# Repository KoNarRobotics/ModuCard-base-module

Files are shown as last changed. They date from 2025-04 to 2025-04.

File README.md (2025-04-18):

# ModuCard Base Module

This repository provides a template design for creating modules in the ModuCard system. Each module is designed to seamlessly interface with the [ModuCard backplane](https://github.com/KoNarRobotics/ModuCard-backplane), enabling a modular and expandable robotics platform.
obraz

## Used tools:


## Features:

### Power section
- **Input voltage:** 12V from the backplane.  
- **Output voltage:** 3.3V @ 0.5A.

### ST-LINK
- Built-in **ST-LINK** connected to the backplane via USB interface.  
- Enables programming and debugging of the onboard MCU.

### CAN interface
- Two independent CAN buses: **CAN1** and **CAN2**.  
- Both connect with the backplane to facilitate communication between the onboard MCU and other modules in the system.

# How to Create a new module from this template
1. **Create a new repository**
2. **Copy files from this repository** to your new repository.  
3. **Rename the files:**
   - `base-module.kicad_pcb` → `<your-board-name>.kicad_pcb`
   - `base-module.kicad_sch` → `<your-board-name>.kicad_sch`
   - `base-module.kicad_pro` → `<your-board-name>.kicad_pro`
4. **Open the project** in KiCad.  
5. **Update page settings** in the schematic and PCB:
   - Change the **Title** to `ModuCard <your project name>`.  
   - Edit **Comment 2** to include your name in the `<author>` field.
6. Enjoy implementing your project!

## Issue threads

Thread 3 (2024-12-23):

Base Module Schematic

ArthorH, 2024-12-23:

Dominik-Workshop, 2025-02-13:
Updated components on the schematic to be from JLC component library.
Finalized schematic, cleared ERC errors. Schematic needs to be double checked, but any possible fixes will be done on branch #2, as mistakes in the schematic might come out during layout.

Dominik-Workshop, 2025-02-13:
Created MR #6 and merged to main.
Closing this issue.

Closed 2025-02-13.

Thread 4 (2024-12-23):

Base Module Verification

ArthorH, 2024-12-23:
PCB was finished in [#2]. It needs to be verified, that there are no mistakes in the design.

Dominik-Workshop, 2025-02-18:
Cleaned up the shematic, fixed found issues. Created MR [#9], merged to main

Closed 2025-02-18.

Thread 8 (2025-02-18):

Fix front panel component libraries

ArthorH, 2025-02-18:
Fix issues with footprint libraries

ArthorH, 2025-02-19:
Fixed all issues, added a new silkscreen, changed the designated spots for board information and boardhouse information, and added a QR code to the PCB.

Closed 2025-02-19.

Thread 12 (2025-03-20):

Fix issues found during bringup

Dominik-Workshop, 2025-03-20:
Following issues were found during bringup of [nav module](https://github.com/KoNarRobotics/ModuCard-nav-module) which is based on this template:
- no GND testpoints (minor issue)
- power indicator LEDs are too bright
- USB not working due to TVS's big capacitance (`U200` and `U802`)
- ST-LINK working only intermittently, due to wrong load capacitors for crystal osclillator (change `C707` and `C708` 33pF -> 18pF)
- ST-LINK LEDs are too dim

These issues should be fixed in next revision.

X-Lemon-X, 2025-03-26:
Tranzistor from stlinka usb-renum is making st link not pop up on USB

Dominik-Workshop, 2025-03-29:
`ST-LINK`'s resonator `Y700` has no `MPN`. We need to choose specific part, and only then we can change it's load capacitors.

Dominik-Workshop, 2025-04-13:
`Y700`'s MPN `3225-8.00-20-10-10/4B` (LCSC Part #  `C7424755`)

Dominik-Workshop, 2025-04-17:
It turned out, `Y700` that was sodlered wasn't `3225-8.00-20-10-10/4B`, and the one that was soldered had `10pF` of load capacitance.
Added `Y700` MPN info: `3225-8.00-20-10-10/4B` in the KiCad project. Next time we need to ensure we solder the correct resonator.

Closed 2025-04-17.

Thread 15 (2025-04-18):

Change name to ModuCard-BM-STM32H750VBT6 to avoid confusion

ArthorH, 2025-04-18:
Simple name change in order to avoid confusion

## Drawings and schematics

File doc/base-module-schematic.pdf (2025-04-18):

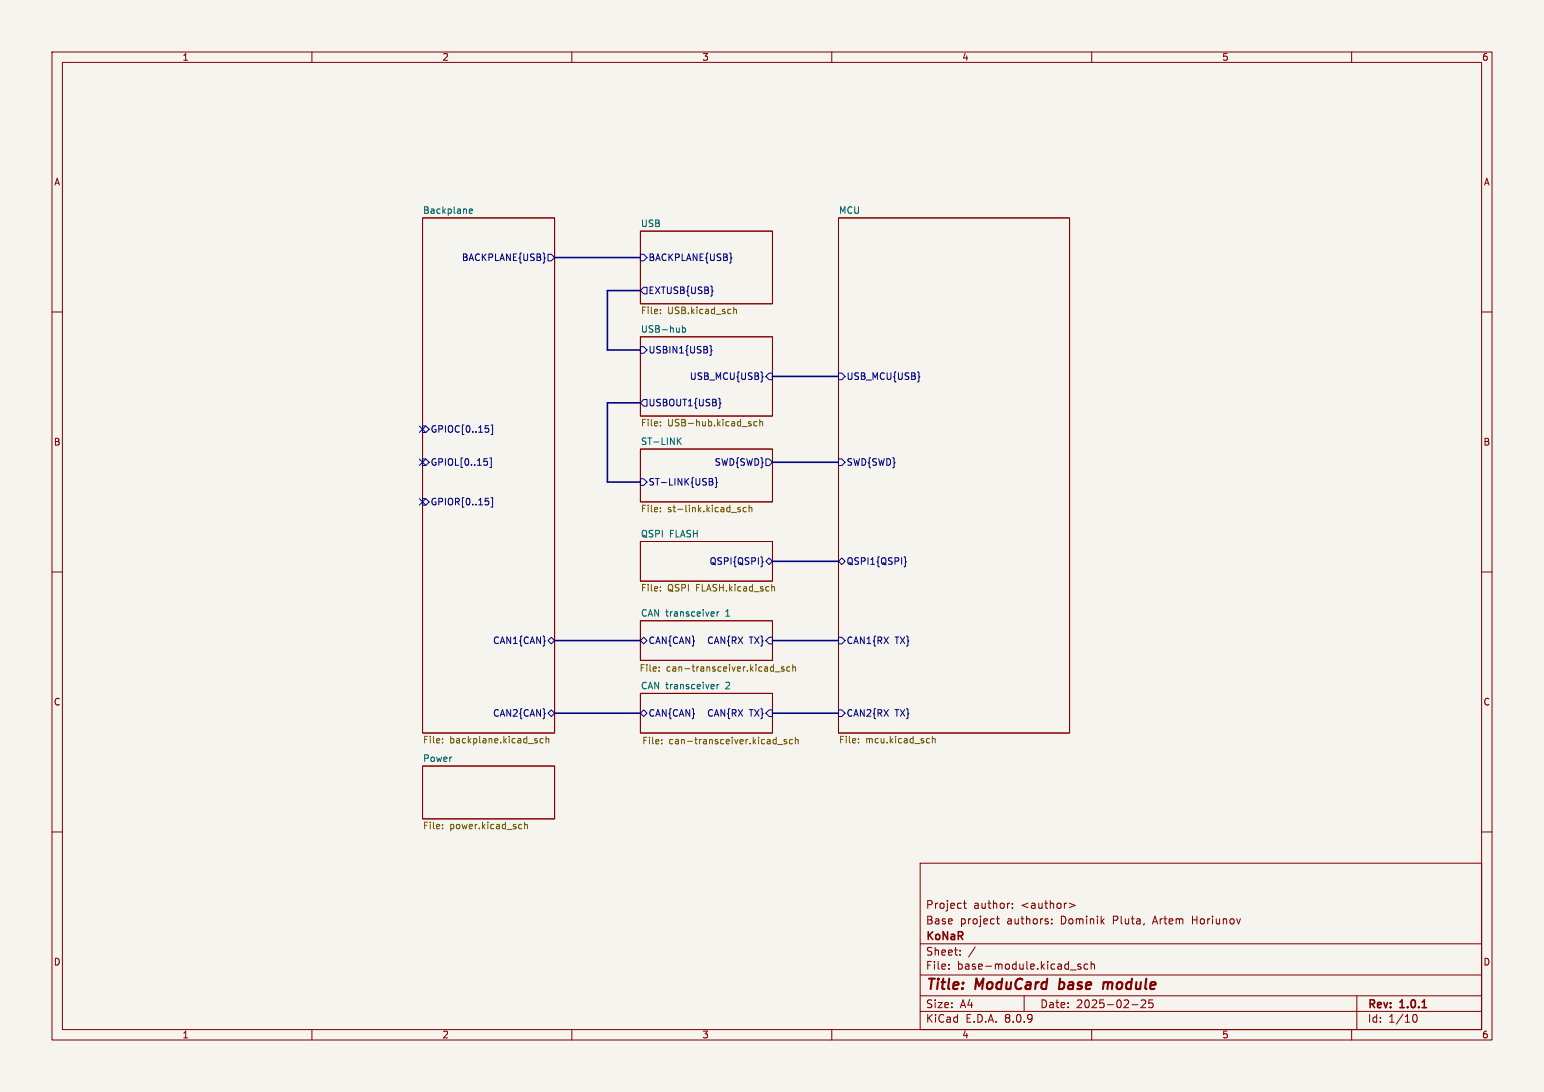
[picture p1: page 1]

Backplane File: backplane.kicad_sch
File: USB.kicad_sch QSPI{QSPI} QSPI FLASH

File: QSPI FLASH.kicad_sch USBIN1{USB}

SWD{SWD} ST-LINK

File: base-module.kicad_sch Sheet: / KoNaR

Id: 1/10 Title: ModuCard base module

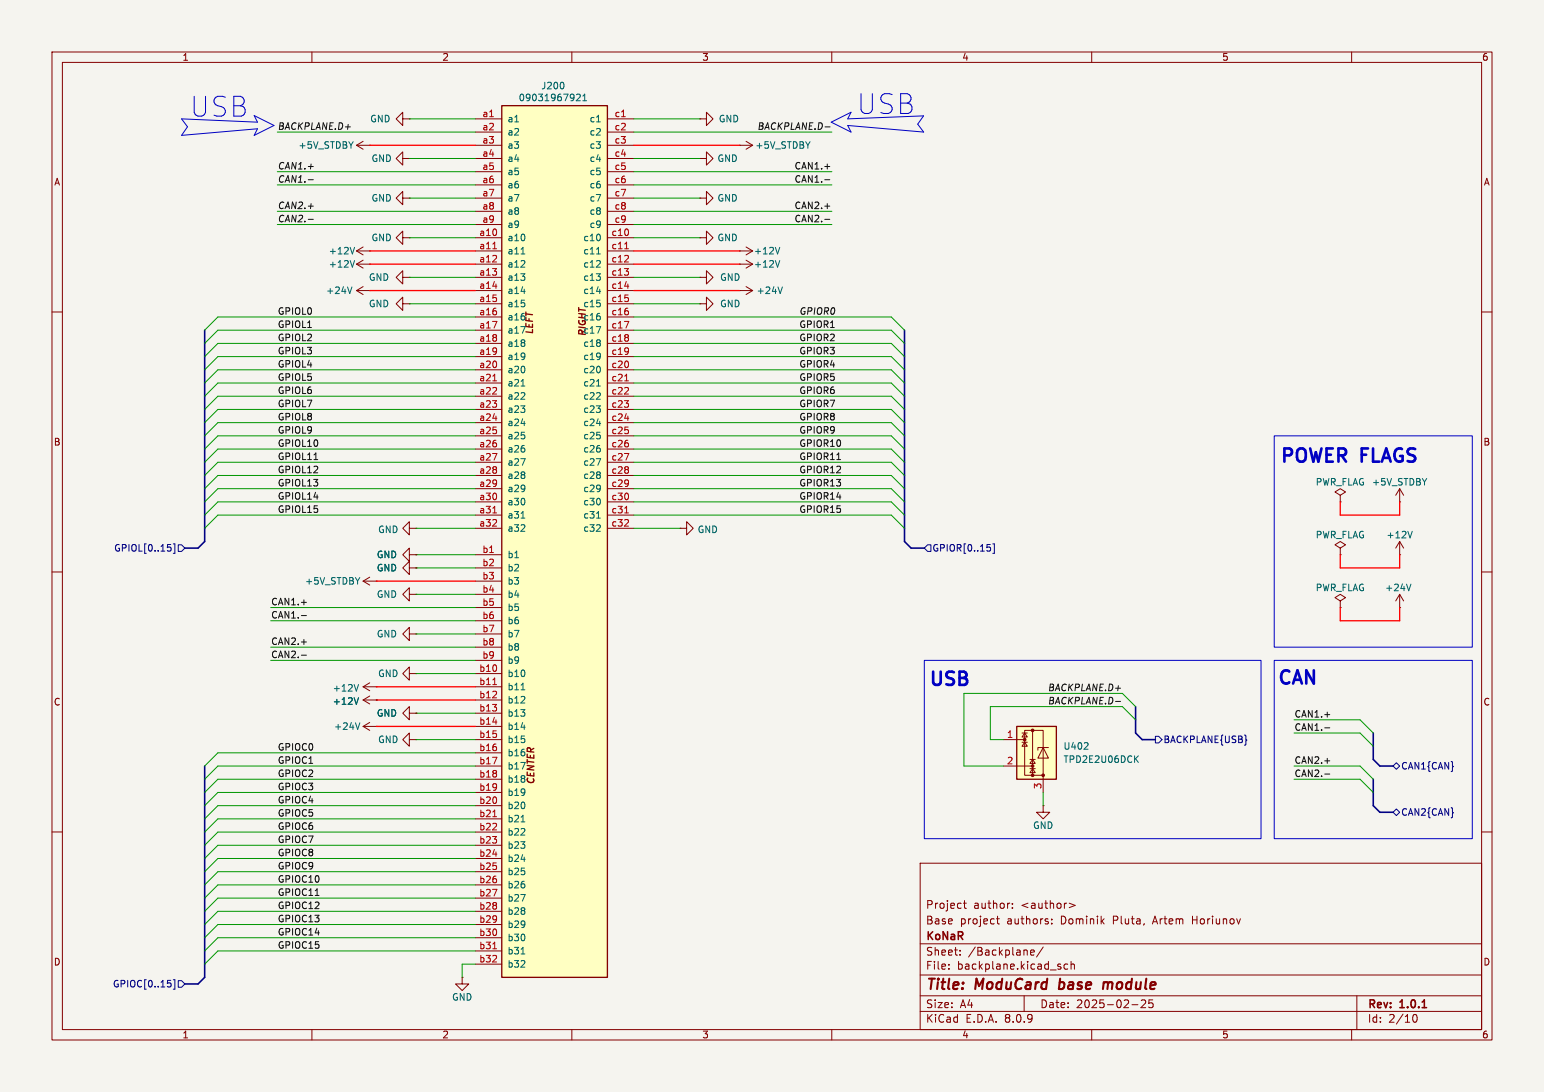
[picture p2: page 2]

GND GND

+24V GND GND GND GNDGND GND

File: backplane.kicad_sch Sheet: /Backplane/ KoNaR

Id: 2/10 Title: ModuCard base module

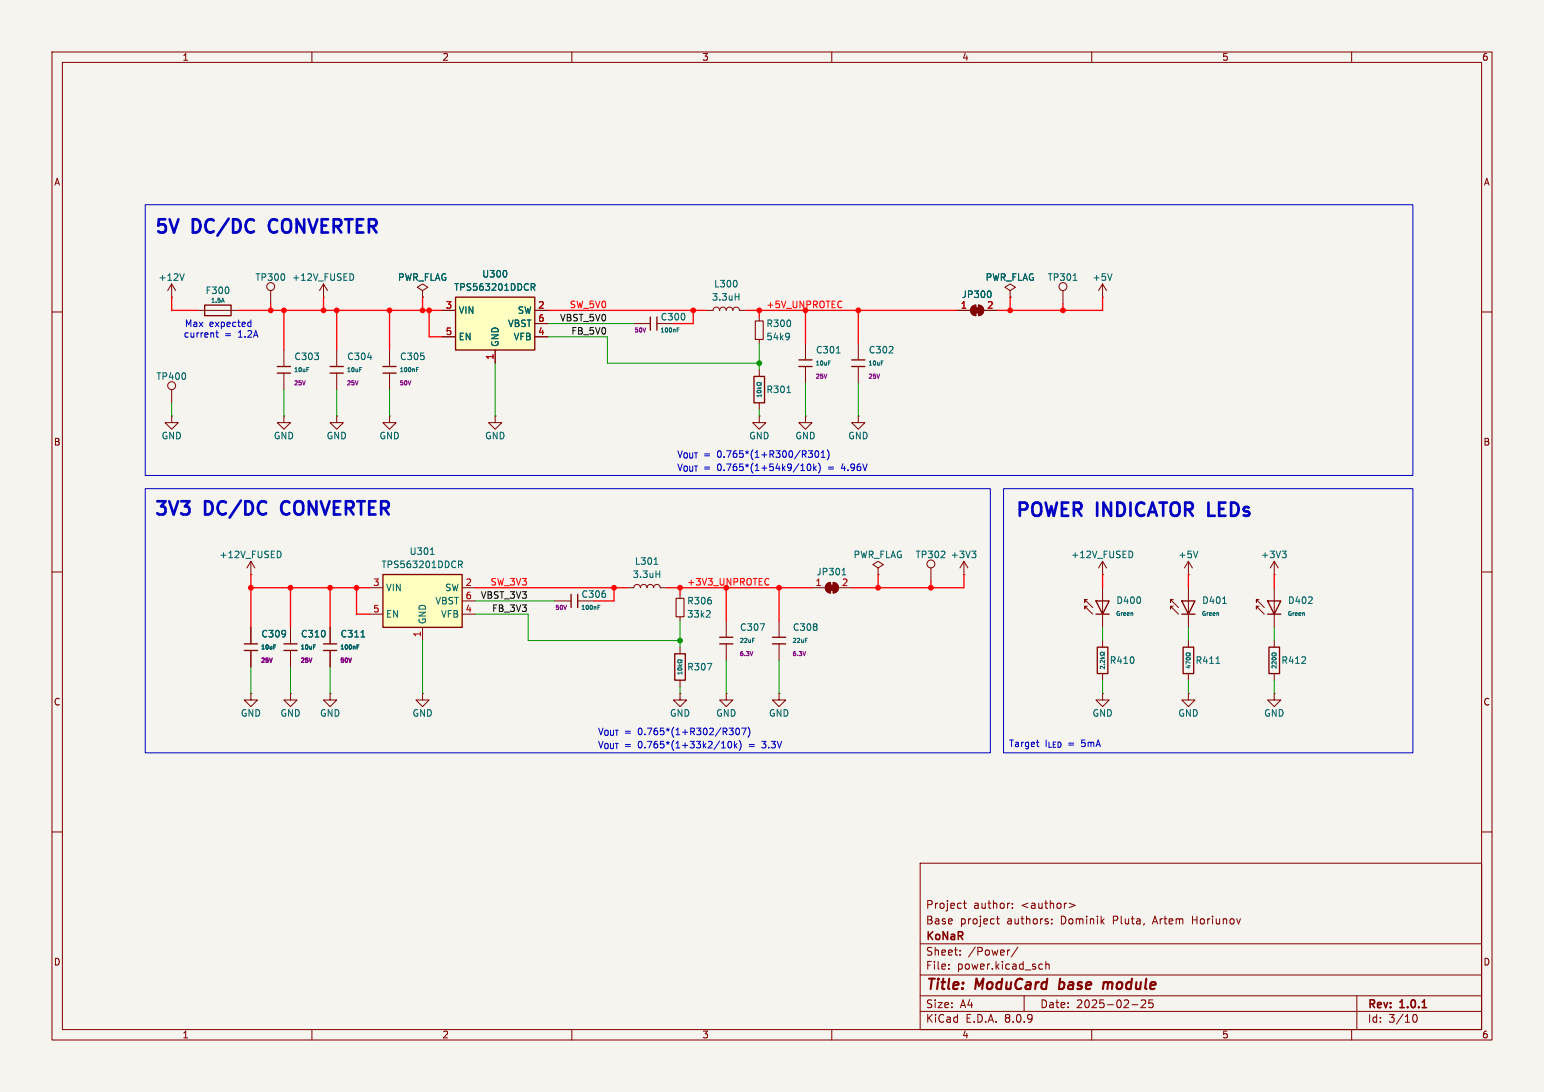
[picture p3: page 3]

1 SW 2 VIN 3 VFB 4 EN 5 VBST 6 U300 TPS563201DDCR

1 SW 2 VIN 3 VFB 4 EN 5 VBST 6 PWR_FLAG

1 SW 2 VIN 3 VFB 4 EN 5 VBST 6 U301 TPS563201DDCR GNDGND

File: power.kicad_sch Sheet: /Power/ KoNaR

Id: 3/10 Title: ModuCard base module

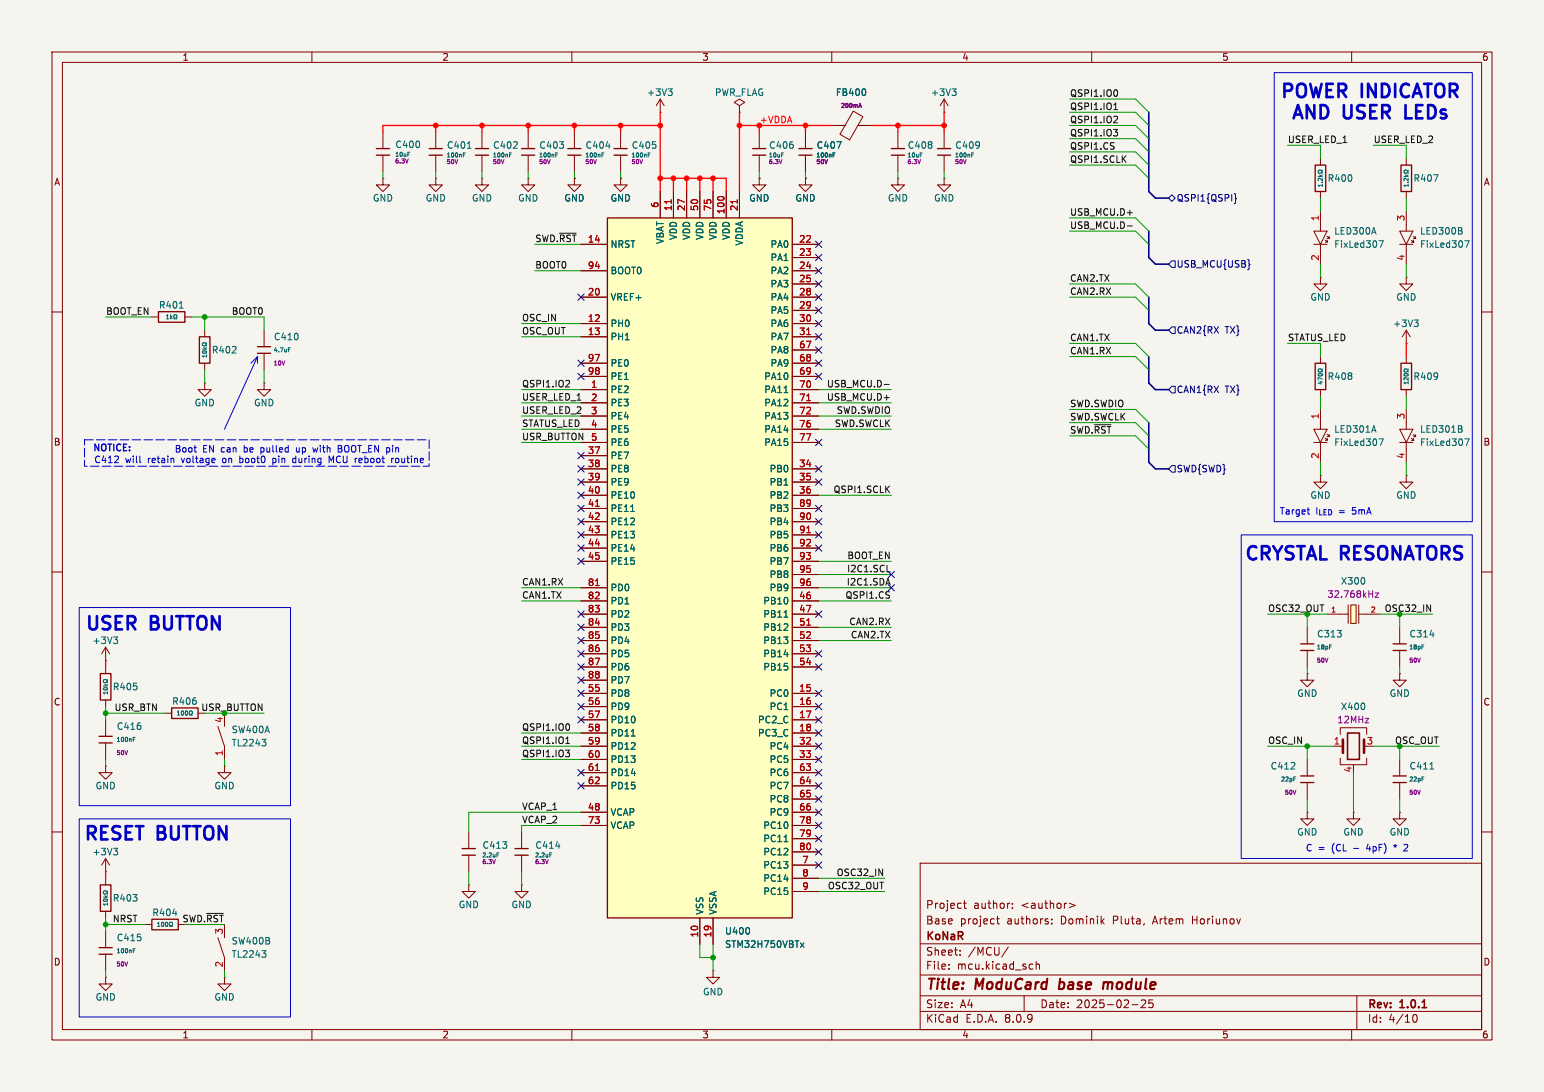
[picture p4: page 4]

File: mcu.kicad_sch Sheet: /MCU/ KoNaR

Id: 4/10 Title: ModuCard base module

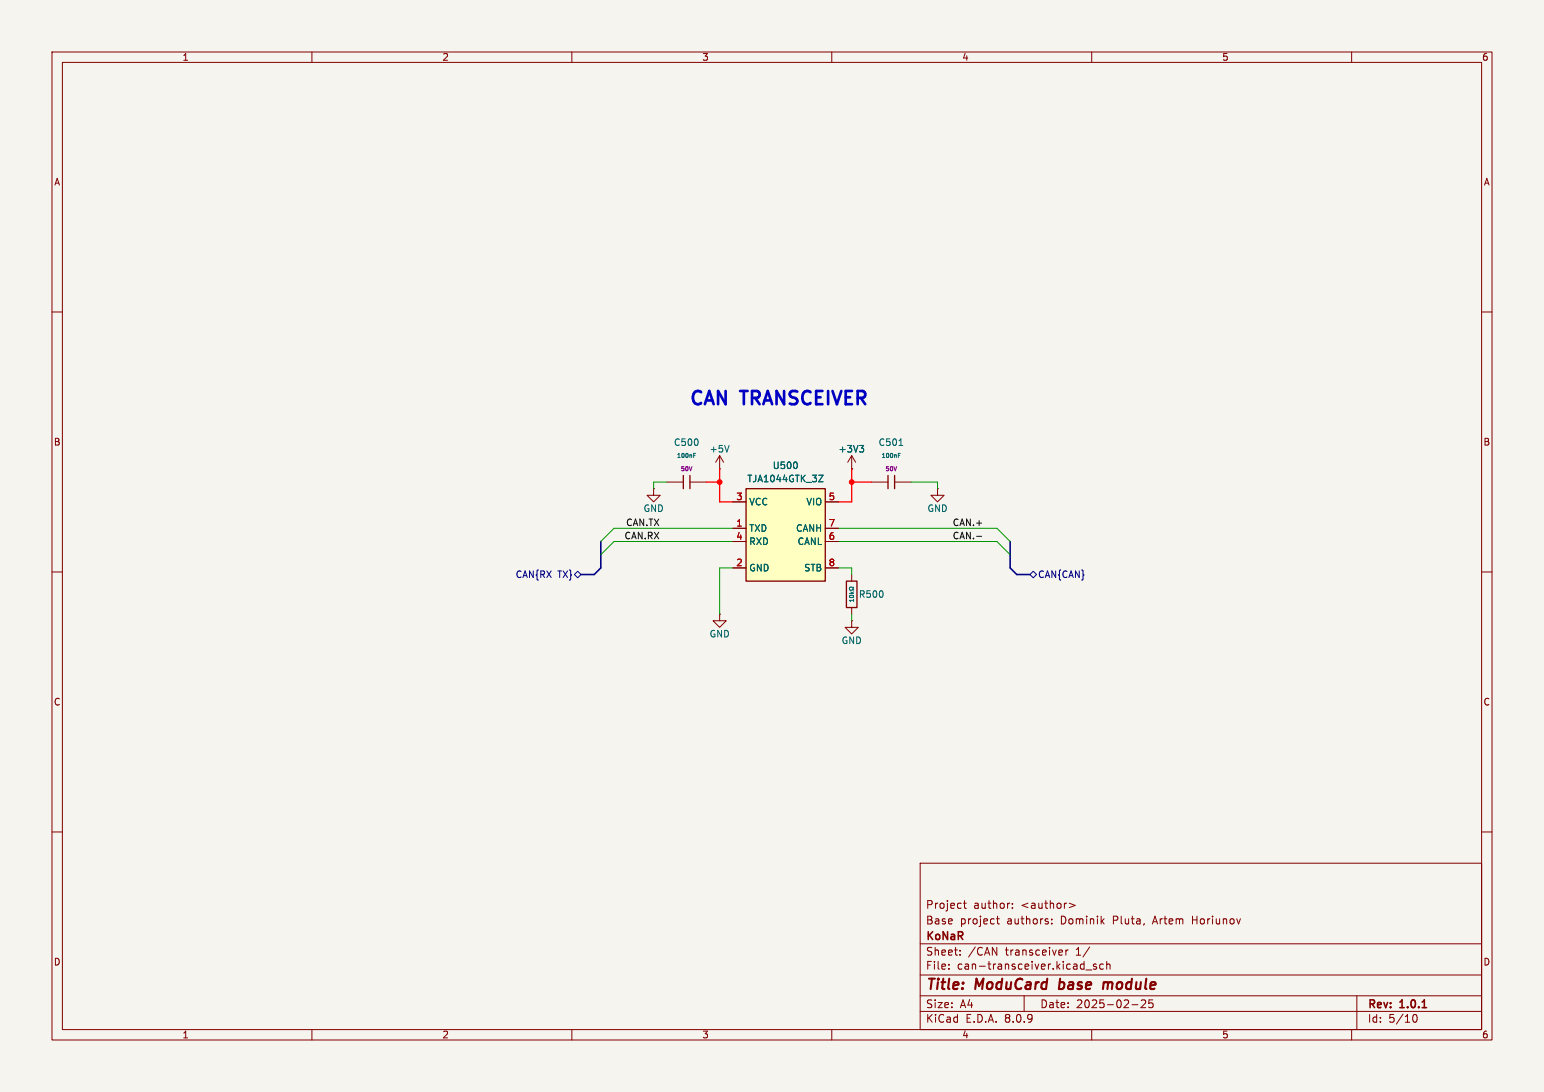
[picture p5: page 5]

Id: 5/10 Title: ModuCard base module

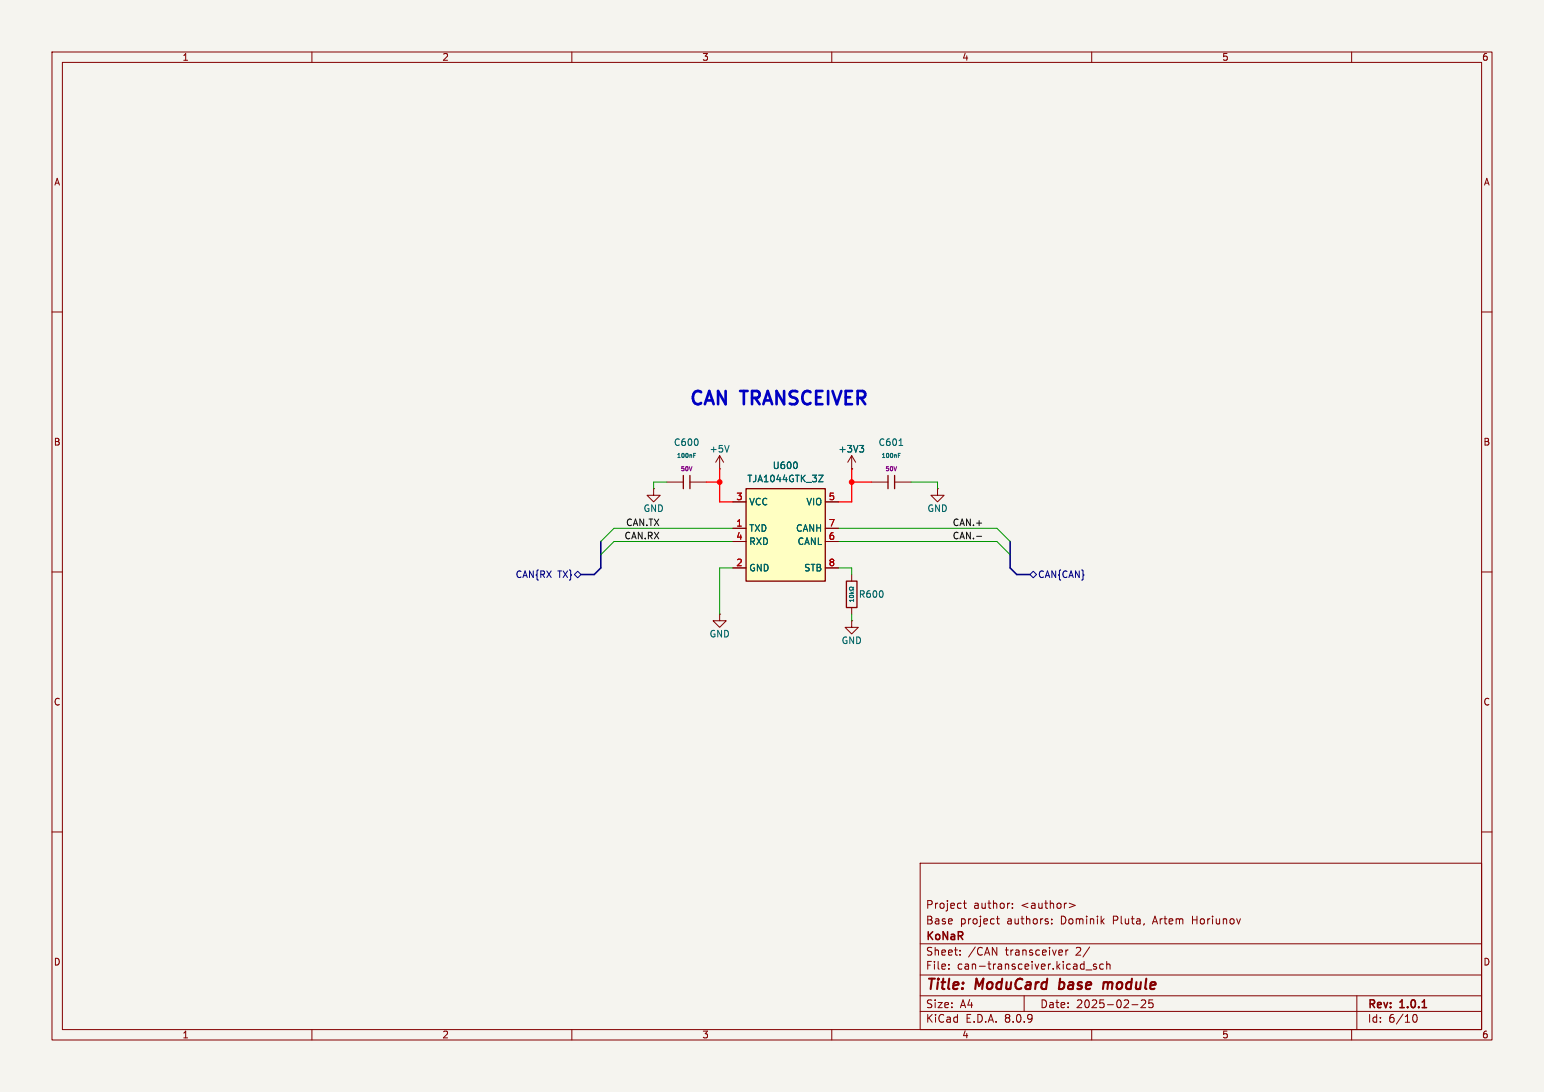
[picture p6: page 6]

Id: 6/10 Title: ModuCard base module

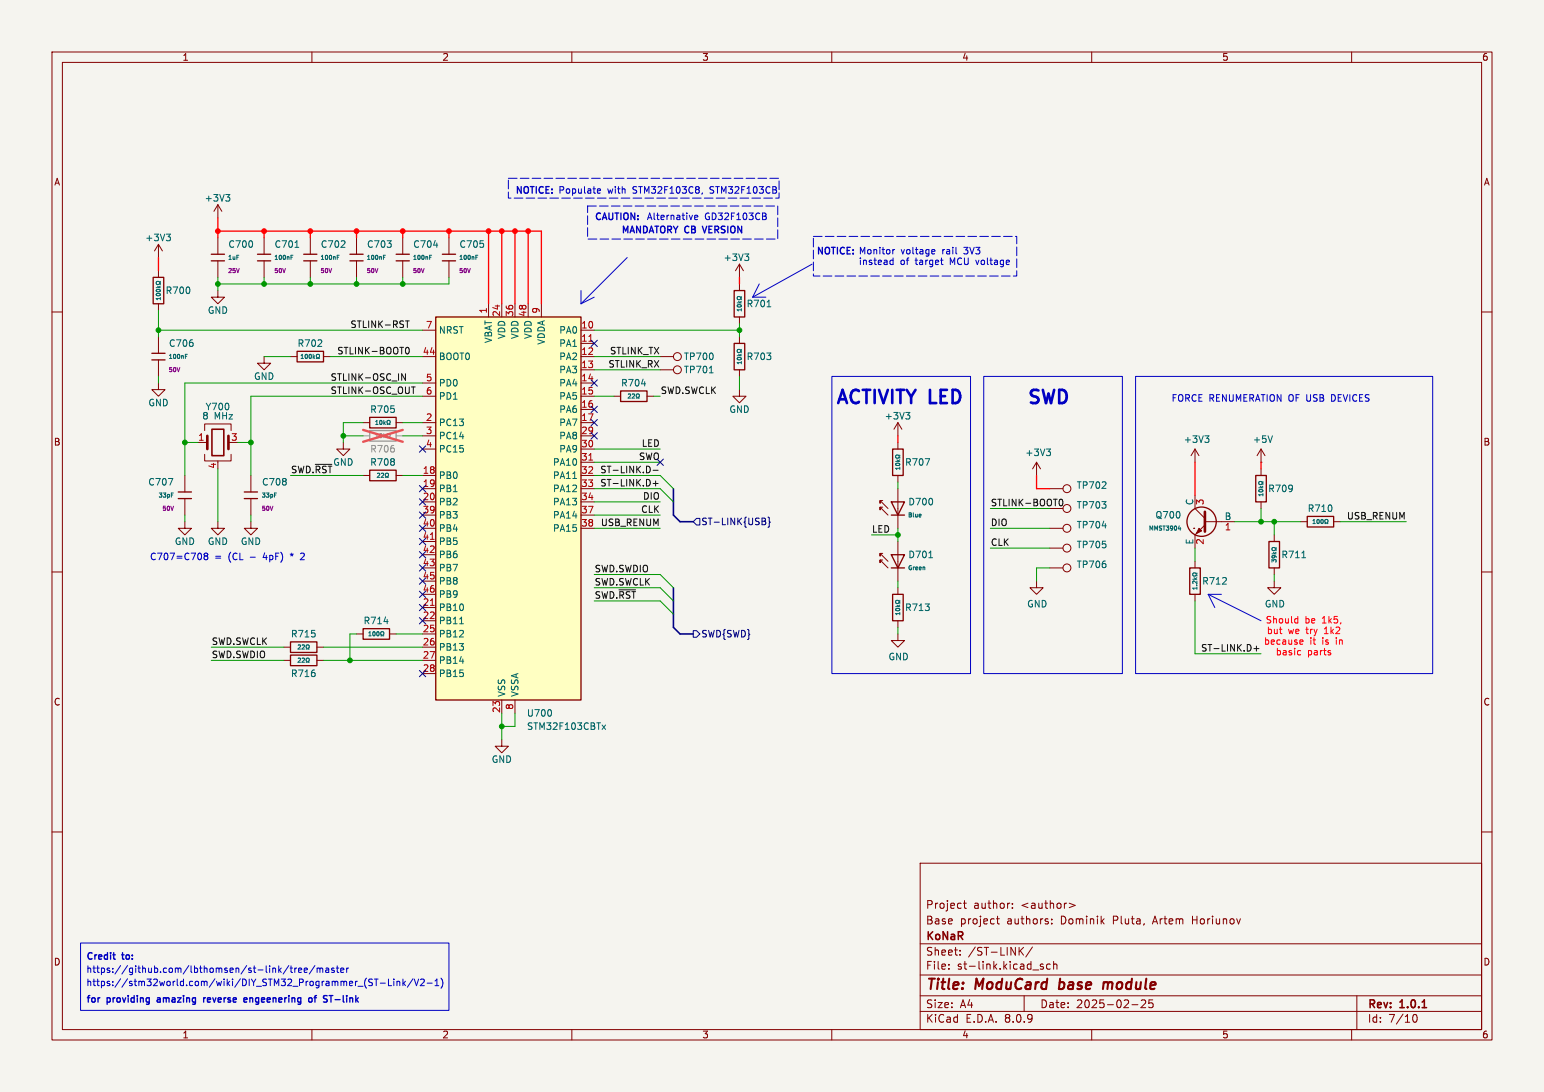
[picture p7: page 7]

instead of target MCU voltage

1 PA0 10 PA1 11 PA2 12 PA3 13 PA4 14 PA5 15 PA6 16 PA7 17 PB0 18 PB1 19 PC13 2 PB2 20 PB10 21 PB11 22 VSS 23 VDD 24 PB12 25 PB13 26 PB14 27 PB15 28 PA8 29 PC14 3 PA9 30 PA10 31 PA11 32 PA12 33 PA13 34 VDD 36 PA14 37 PA15 38 PB3 39 PC15 4 PB4 40 PB5 41 PB6 42 PB7 43 BOOT0 44 PB8 45 PB9 46 VDD 48 PD0 5 PD1 6 NRST 7 VSSA

ST-LINK{USB} STLINK-RST

ST-LINK.D- SWD.SWCLK

SWD.SWDIO
ST-LINK.D+ SWD.SWCLK
SWD.~{RST}

because it is in

basic parts https://stm32world.com/wiki/DIY_STM32_Programmer_(ST-Link/V2-1)

File: st-link.kicad_sch Sheet: /ST-LINK/ KoNaR

Credit to: https://github.com/lbthomsen/st-link/tree/master

Id: 7/10 Title: ModuCard base module

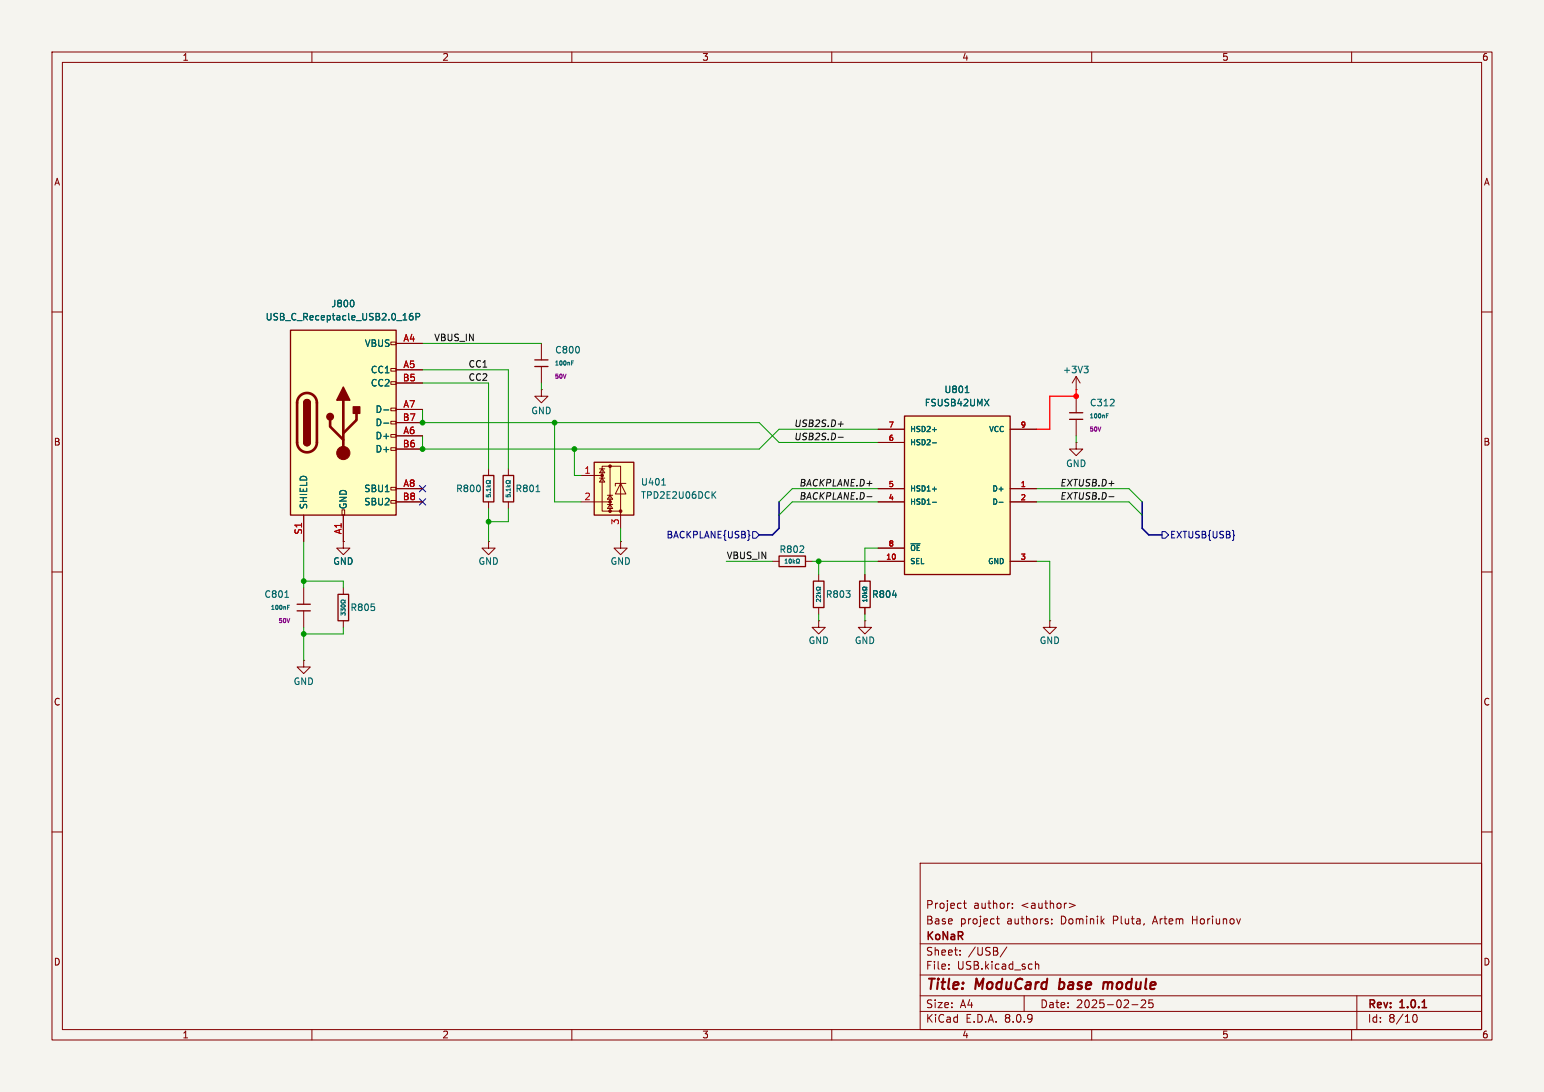
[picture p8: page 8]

File: USB.kicad_sch Sheet: /USB/ KoNaR

Id: 8/10 Title: ModuCard base module

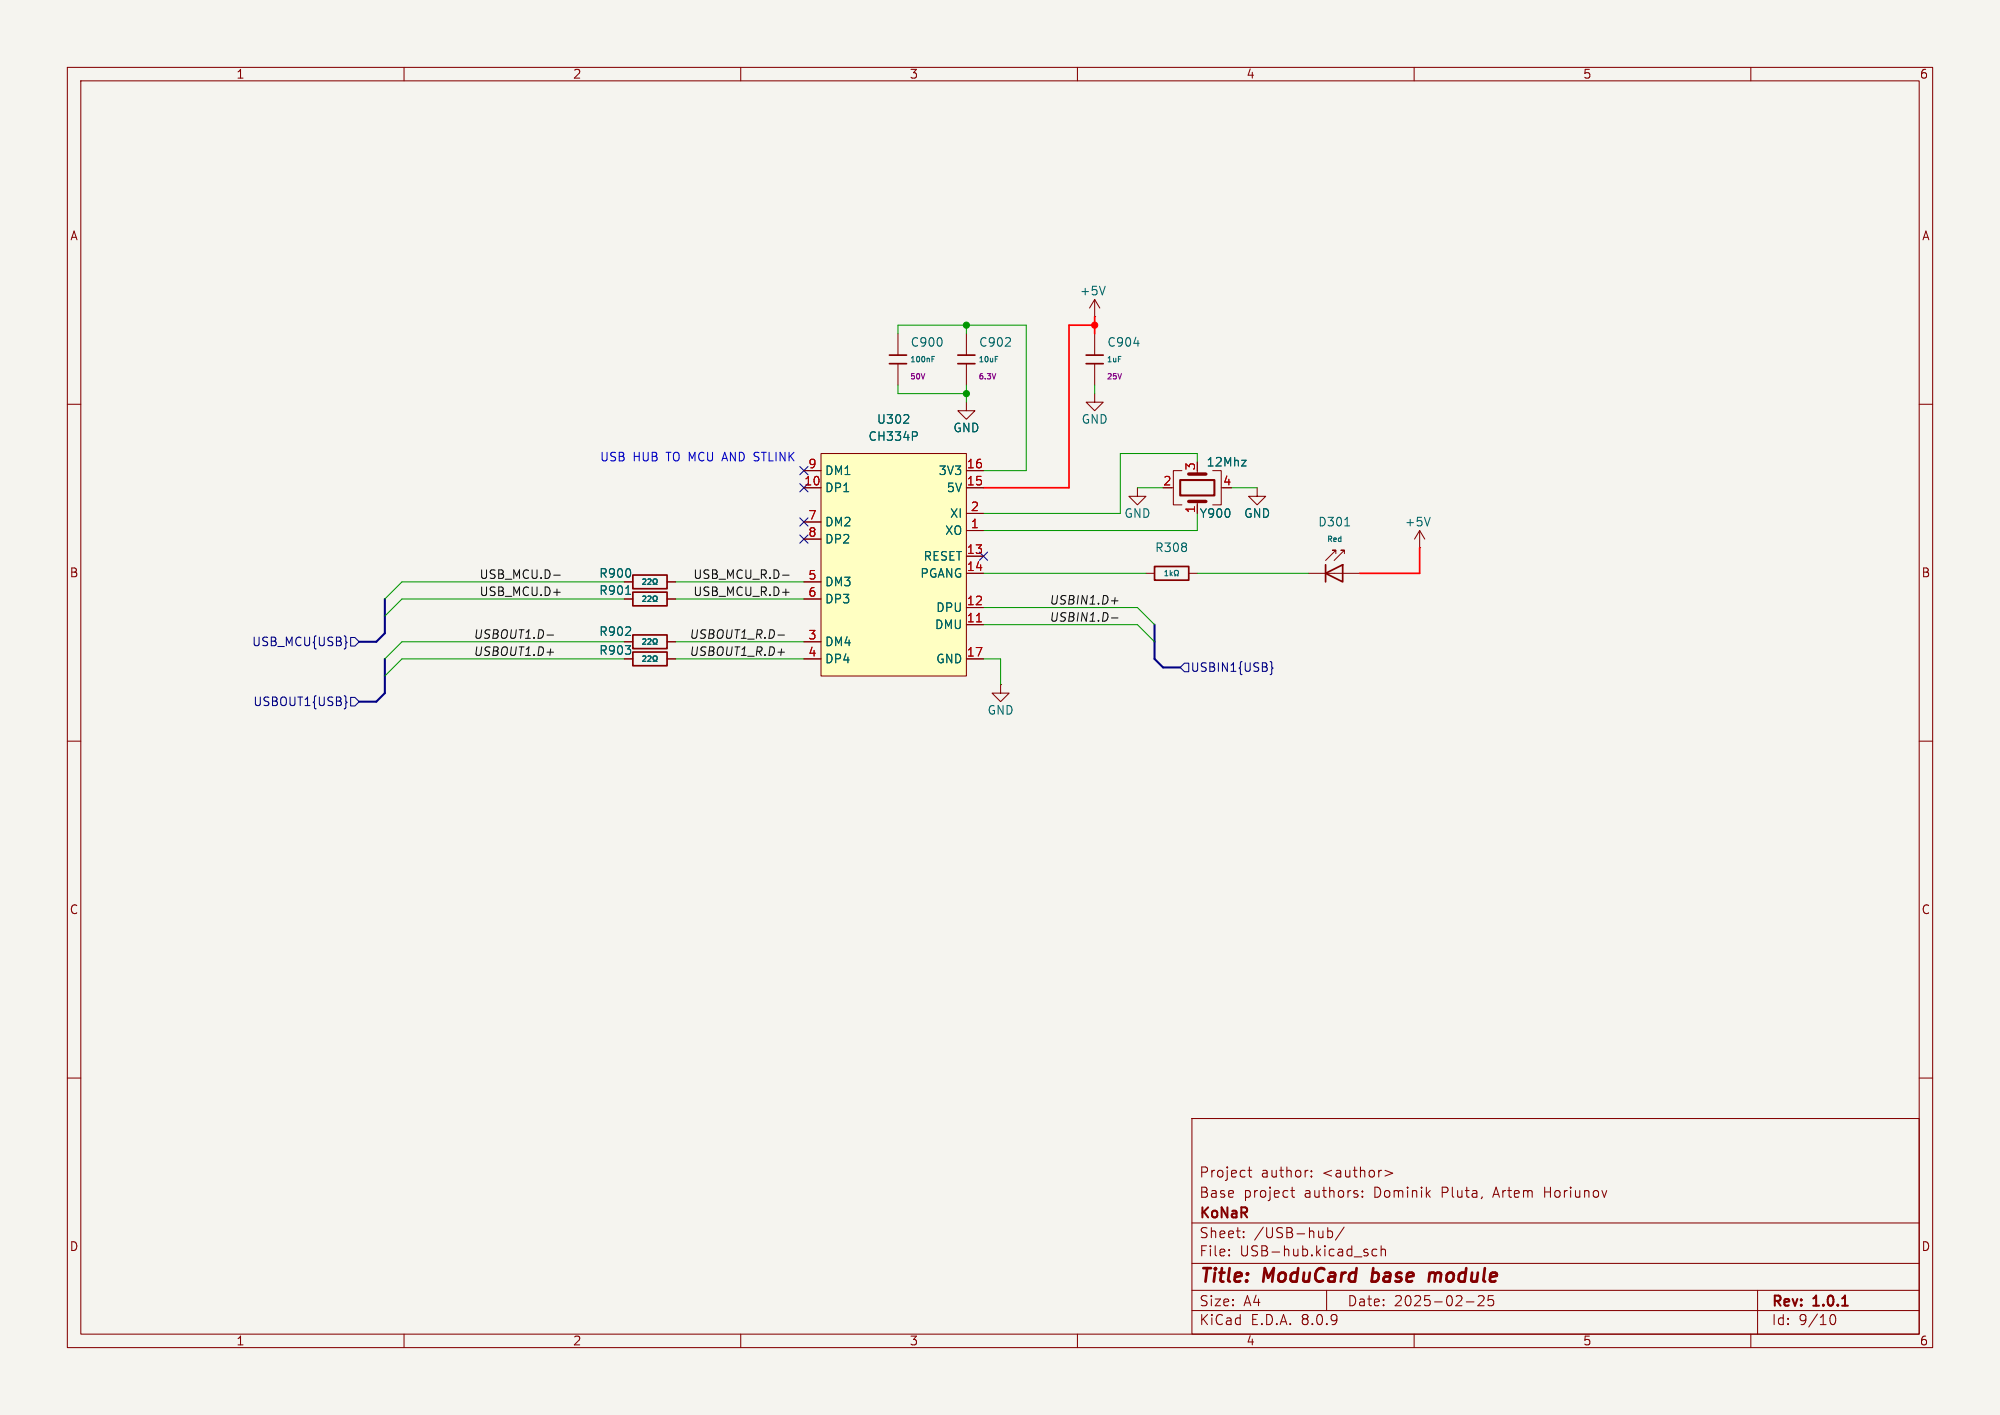
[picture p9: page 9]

File: USB-hub.kicad_sch Sheet: /USB-hub/ KoNaR

Id: 9/10 Title: ModuCard base module

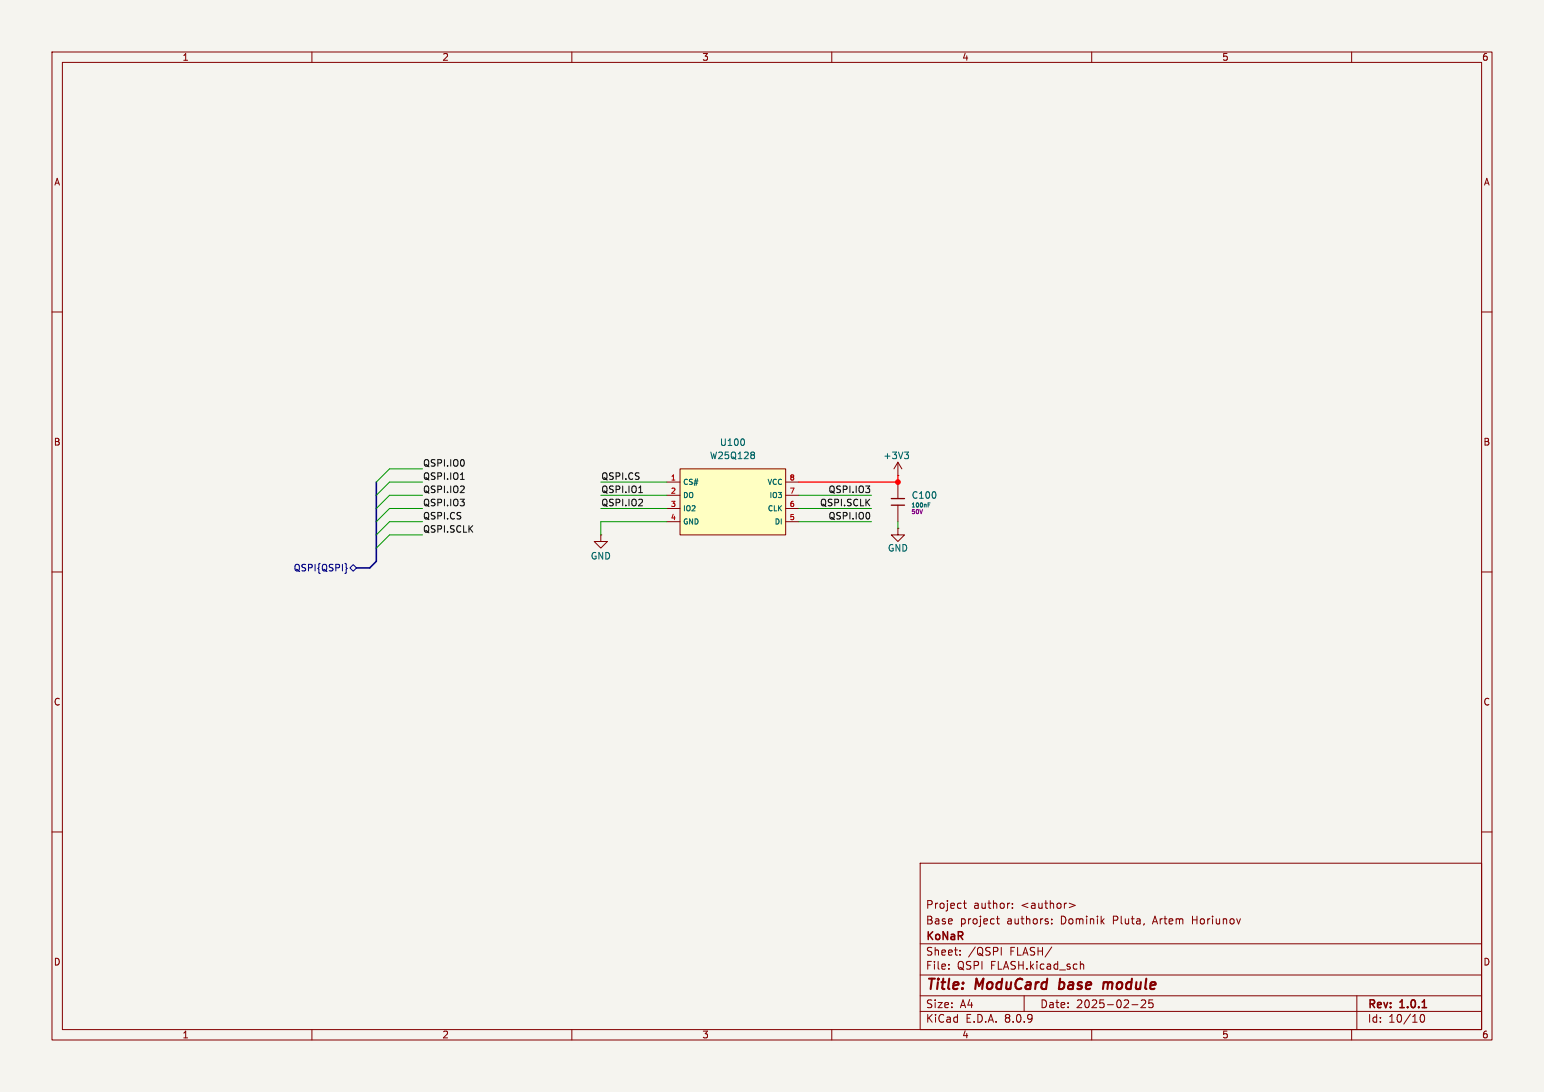
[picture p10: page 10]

Id: 10/10 Title: ModuCard base module

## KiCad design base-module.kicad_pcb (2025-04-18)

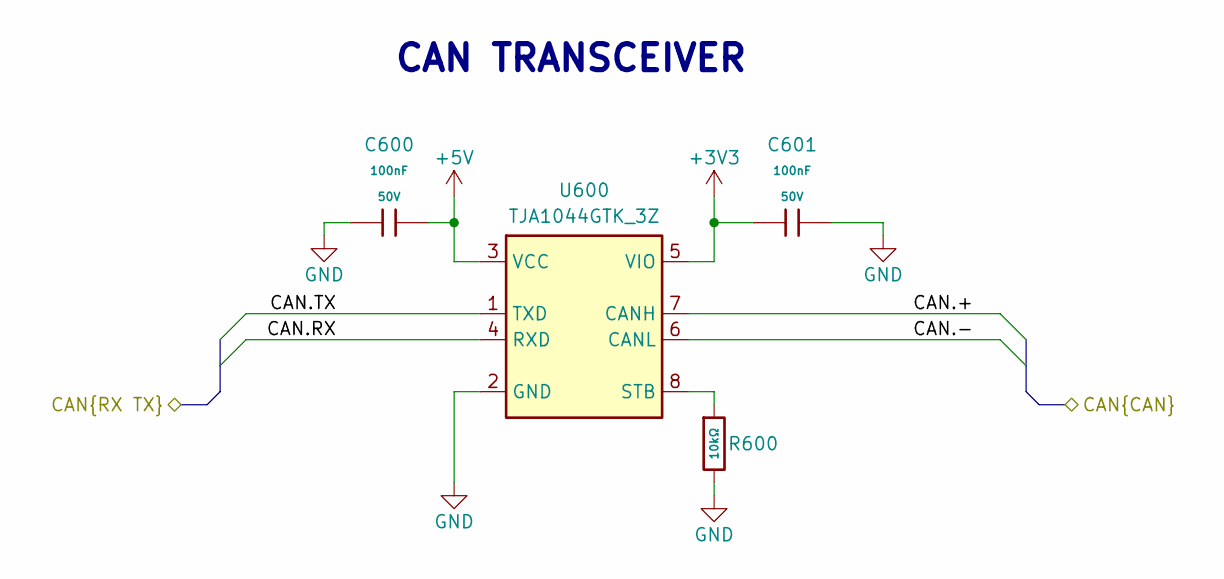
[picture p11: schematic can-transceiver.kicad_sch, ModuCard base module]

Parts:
C600, C601: 100nF; C_0402; Voltage Rated 50V; Tolerance ±10%; Part CL05B104KB54PNC; LCSC C307331
R600: 10kΩ; R_0402; Overload Voltage (Max) 50V; Tolerance ±1%; Part 0402WGF1002TCE; LCSC C25744
U600: TJA1044GTK_3Z; HVSON-8-1EP_3x3mm_P0.65mm_EP1.6x2.4mm; Manufacturer_Part_Number TJA1044GTK/3Z

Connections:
+3V3: C601.1, U600.5 (VIO); also elsewhere on the board
+5V: C600.2, U600.3 (VCC); also elsewhere on the board
/Backplane/CAN2.+: U600.7 (CANH); also elsewhere on the board
/Backplane/CAN2.-: U600.6 (CANL); also elsewhere on the board
/CAN transceiver 2/CAN.RX: U600.4 (RXD); also elsewhere on the board
/CAN transceiver 2/CAN.TX: U600.1 (TXD); also elsewhere on the board
GND: C600.1, C601.2, R600.2, U600.2 (GND), U600.9 (EP); also elsewhere on the board
unnamed: R600.1, U600.8 (STB)

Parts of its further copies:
C500, C501: 100nF; C_0402; Voltage Rated 50V; Tolerance ±10%; Part CL05B104KB54PNC; LCSC C307331
R500: 10kΩ; R_0402; Overload Voltage (Max) 50V; Tolerance ±1%; Part 0402WGF1002TCE; LCSC C25744
U500: TJA1044GTK_3Z; HVSON-8-1EP_3x3mm_P0.65mm_EP1.6x2.4mm; Manufacturer_Part_Number TJA1044GTK/3Z

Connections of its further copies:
+3V3: C501.1, U500.5 (VIO); also elsewhere on the board
+5V: C500.2, U500.3 (VCC); also elsewhere on the board
/Backplane/CAN1.+: U500.7 (CANH); also elsewhere on the board
/Backplane/CAN1.-: U500.6 (CANL); also elsewhere on the board
/CAN transceiver 1/CAN.RX: U500.4 (RXD); also elsewhere on the board
/CAN transceiver 1/CAN.TX: U500.1 (TXD); also elsewhere on the board
GND: C500.1, C501.2, R500.2, U500.2 (GND), U500.9 (EP); also elsewhere on the board
unnamed: R500.1, U500.8 (STB)

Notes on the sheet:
CAN TRANSCEIVER

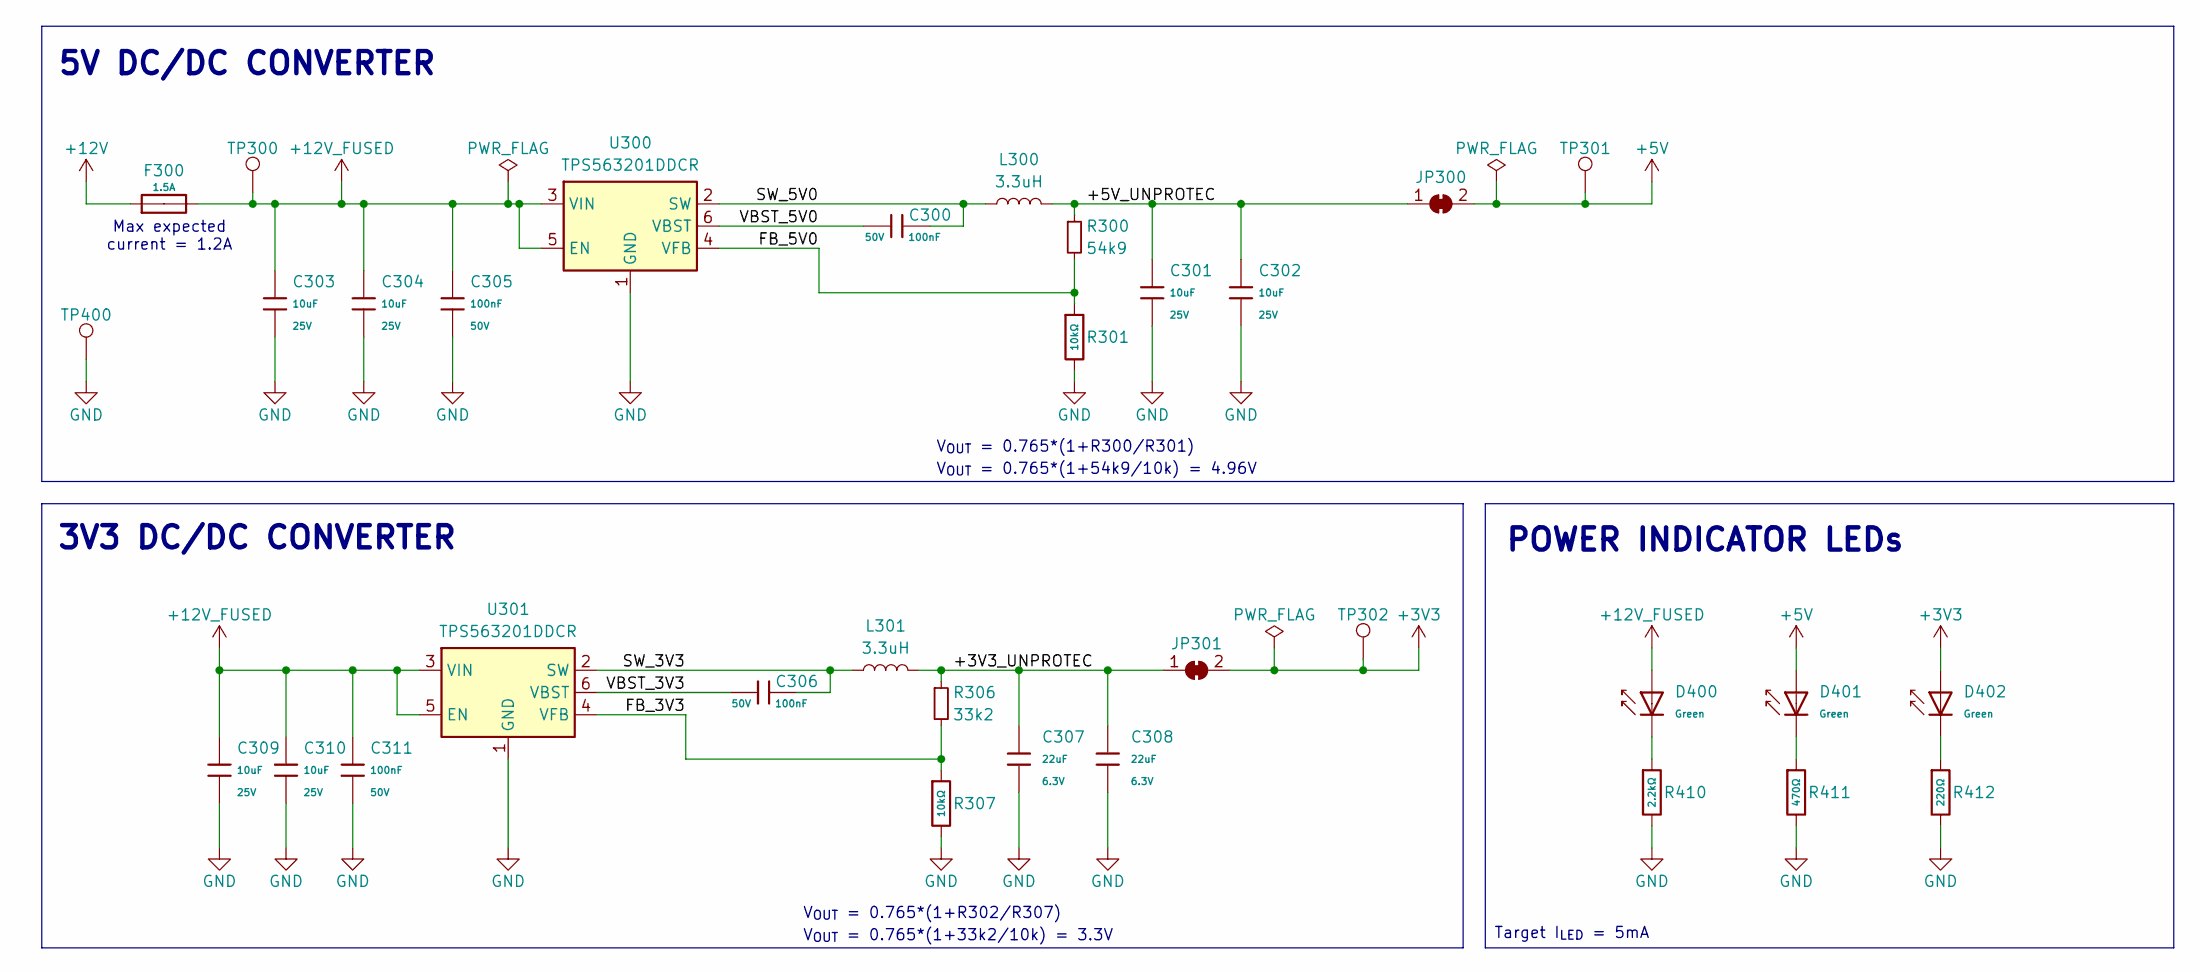
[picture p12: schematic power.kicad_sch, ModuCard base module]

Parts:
C300, C305, C306, C311: 100nF; C_0402; Voltage Rated 50V; Tolerance ±10%; Part CL05B104KB54PNC; LCSC C307331
C301, C302, C303, C304, C309, C310: 10uF; C_0603; Voltage Rated 25V; Tolerance ±20%; Part CL10A106MA8NRNC; LCSC C96446
C307, C308: 22uF; C_0603; Voltage Rated 6.3V; Tolerance ±20%; Part CL10A226MQ8NRNC; LCSC C59461
D400, D401, D402: Green; D_0603; Part 19-217/GHC-YR1S2/6T; LCSC C2986059
F300: 1.5A; F_0603; Part F06F1.5; LCSC C2924957
JP300, JP301: Test Buck Vout; SolderJumper-2_P1.3mm_Open_TrianglePad1.0x1.5mm
L300, L301: 3.3uH; L_Changjiang_FXL0420
R300: 54k9; R_0402
R301, R307: 10kΩ; R_0402; Overload Voltage (Max) 50V; Tolerance ±1%; Part 0402WGF1002TCE; LCSC C25744
R306: 33k2; R_0402
R410: 2.2kΩ; R_0402; Overload Voltage (Max) 50V; Tolerance ±1%; Part 0402WGF2201TCE; LCSC C25879
R411: 470Ω; R_0402; Overload Voltage (Max) 50V; Tolerance ±1%; Part 0402WGF4700TCE; LCSC C25117
R412: 220Ω; R_0402; Overload Voltage (Max) 50V; Tolerance ±1%; Part 0402WGF2200TCE; LCSC C25091
TP300, TP301, TP302, TP400: TestPoint; TestPoint_Pad_D1.0mm
U300, U301: TPS563201DDCR; SOT-23-6

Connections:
+3V3: D402.2, JP301.2 (B), TP302.1; also elsewhere on the board
+5V: D401.2, JP300.2 (B), TP301.1; also elsewhere on the board
+12V: F300.1; also elsewhere on the board
+12V_FUSED: C303.1, C304.1, C305.2, C309.1, C310.1, C311.2, D400.2, F300.2, TP300.1, U300.3 (VIN), U300.5 (EN), U301.3 (VIN), U301.5 (EN)
/Power/+3V3_UNPROTEC: C307.1, C308.1, JP301.1 (A), L301.2, R306.1
/Power/+5V_UNPROTEC: C301.1, C302.1, JP300.1 (A), L300.2, R300.1
/Power/FB_3V3: R306.2, R307.1, U301.4 (VFB)
/Power/FB_5V0: R300.2, R301.1, U300.4 (VFB)
/Power/SW_3V3: C306.2, L301.1, U301.2 (SW)
/Power/SW_5V0: C300.2, L300.1, U300.2 (SW)
/Power/VBST_3V3: C306.1, U301.6 (VBST)
/Power/VBST_5V0: C300.1, U300.6 (VBST)
GND: C301.2, C302.2, C303.2, C304.2, C305.1, C307.2, C308.2, C309.2, C310.2, C311.1, R301.2, R307.2, R410.2, R411.2, R412.2, TP400.1, U300.1 (GND), U301.1 (GND); also elsewhere on the board
unnamed: D400.1, R410.1
unnamed: D401.1, R411.1
unnamed: D402.1, R412.1

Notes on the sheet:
V_{OUT} = 0.765*(1+33k2/10k) = 3.3V
Max expected current = 1.2A
V_{OUT} = 0.765*(1+R302/R307)
Target I_{LED} = 5mA
V_{OUT} = 0.765*(1+R300/R301)
5V DC/DC CONVERTER
V_{OUT} = 0.765*(1+54k9/10k) = 4.96V
POWER INDICATOR LEDs
3V3 DC/DC CONVERTER

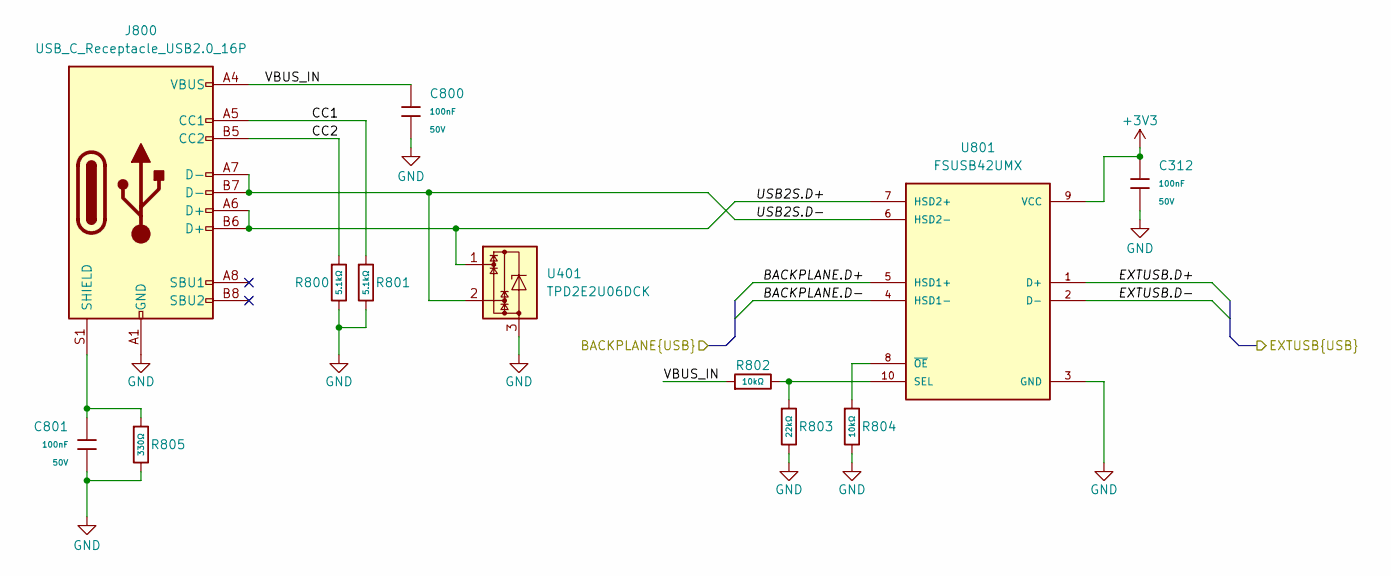
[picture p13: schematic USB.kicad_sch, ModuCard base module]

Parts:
C312, C800, C801: 100nF; C_0402; Voltage Rated 50V; Tolerance ±10%; Part CL05B104KB54PNC; LCSC C307331
J800: USB_C_Receptacle_USB2.0_16P; USB_C_Receptacle_GCT_USB4105-xx-A_16P_TopMnt_Horizontal
R800, R801: 5.1kΩ; R_0402; Overload Voltage (Max) 50V; Tolerance ±1%; Part 0402WGF5101TCE; LCSC C25905
R802, R804: 10kΩ; R_0402; Overload Voltage (Max) 50V; Tolerance ±1%; Part 0402WGF1002TCE; LCSC C25744
R803: 22kΩ; R_0402; Overload Voltage (Max) 50V; Tolerance ±1%; Part 0402WGF2202TCE; LCSC C25768
R805: 330Ω; R_0402; Overload Voltage (Max) 50V; Tolerance ±1%; Part 0402WGF3300TCE; LCSC C25104
U401: TPD2E2U06DCK; SOT-323_SC-70
U801: FSUSB42UMX; UQFN-10_1.4x1.8mm_P0.4mm; PARTREV 1.25

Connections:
+3V3: C312.1, U801.9 (VCC); also elsewhere on the board
/Backplane/BACKPLANE.D+: U801.5 (HSD1+); also elsewhere on the board
/Backplane/BACKPLANE.D-: U801.4 (HSD1-); also elsewhere on the board
/USB-hub/USBIN1.D+: U801.1 (D+); also elsewhere on the board
/USB-hub/USBIN1.D-: U801.2 (D-); also elsewhere on the board
/USB/CC1: J800.A5 (CC1), R801.1
/USB/CC2: J800.B5 (CC2), R800.1
/USB/USB2S.D+: J800.A6 (D+), J800.B6 (D+), U401.1, U801.7 (HSD2+)
/USB/USB2S.D-: J800.A7 (D-), J800.B7 (D-), U401.2, U801.6 (HSD2-)
/USB/VBUS_IN: C800.1, J800.A4 (VBUS), J800.A9 (VBUS), J800.B4 (VBUS), J800.B9 (VBUS), R802.1
GND: C312.2, C800.2, C801.2, J800.A1 (GND), J800.A12 (GND), J800.B1 (GND), J800.B12 (GND), R800.2, R801.2, R803.2, R804.2, R805.2, U401.3, U801.3 (GND); also elsewhere on the board
unnamed: C801.1, J800.S1 (SHIELD), R805.1
unnamed: R802.2, R803.1, U801.10 (SEL)
unnamed: R804.1, U801.8 (~OE)

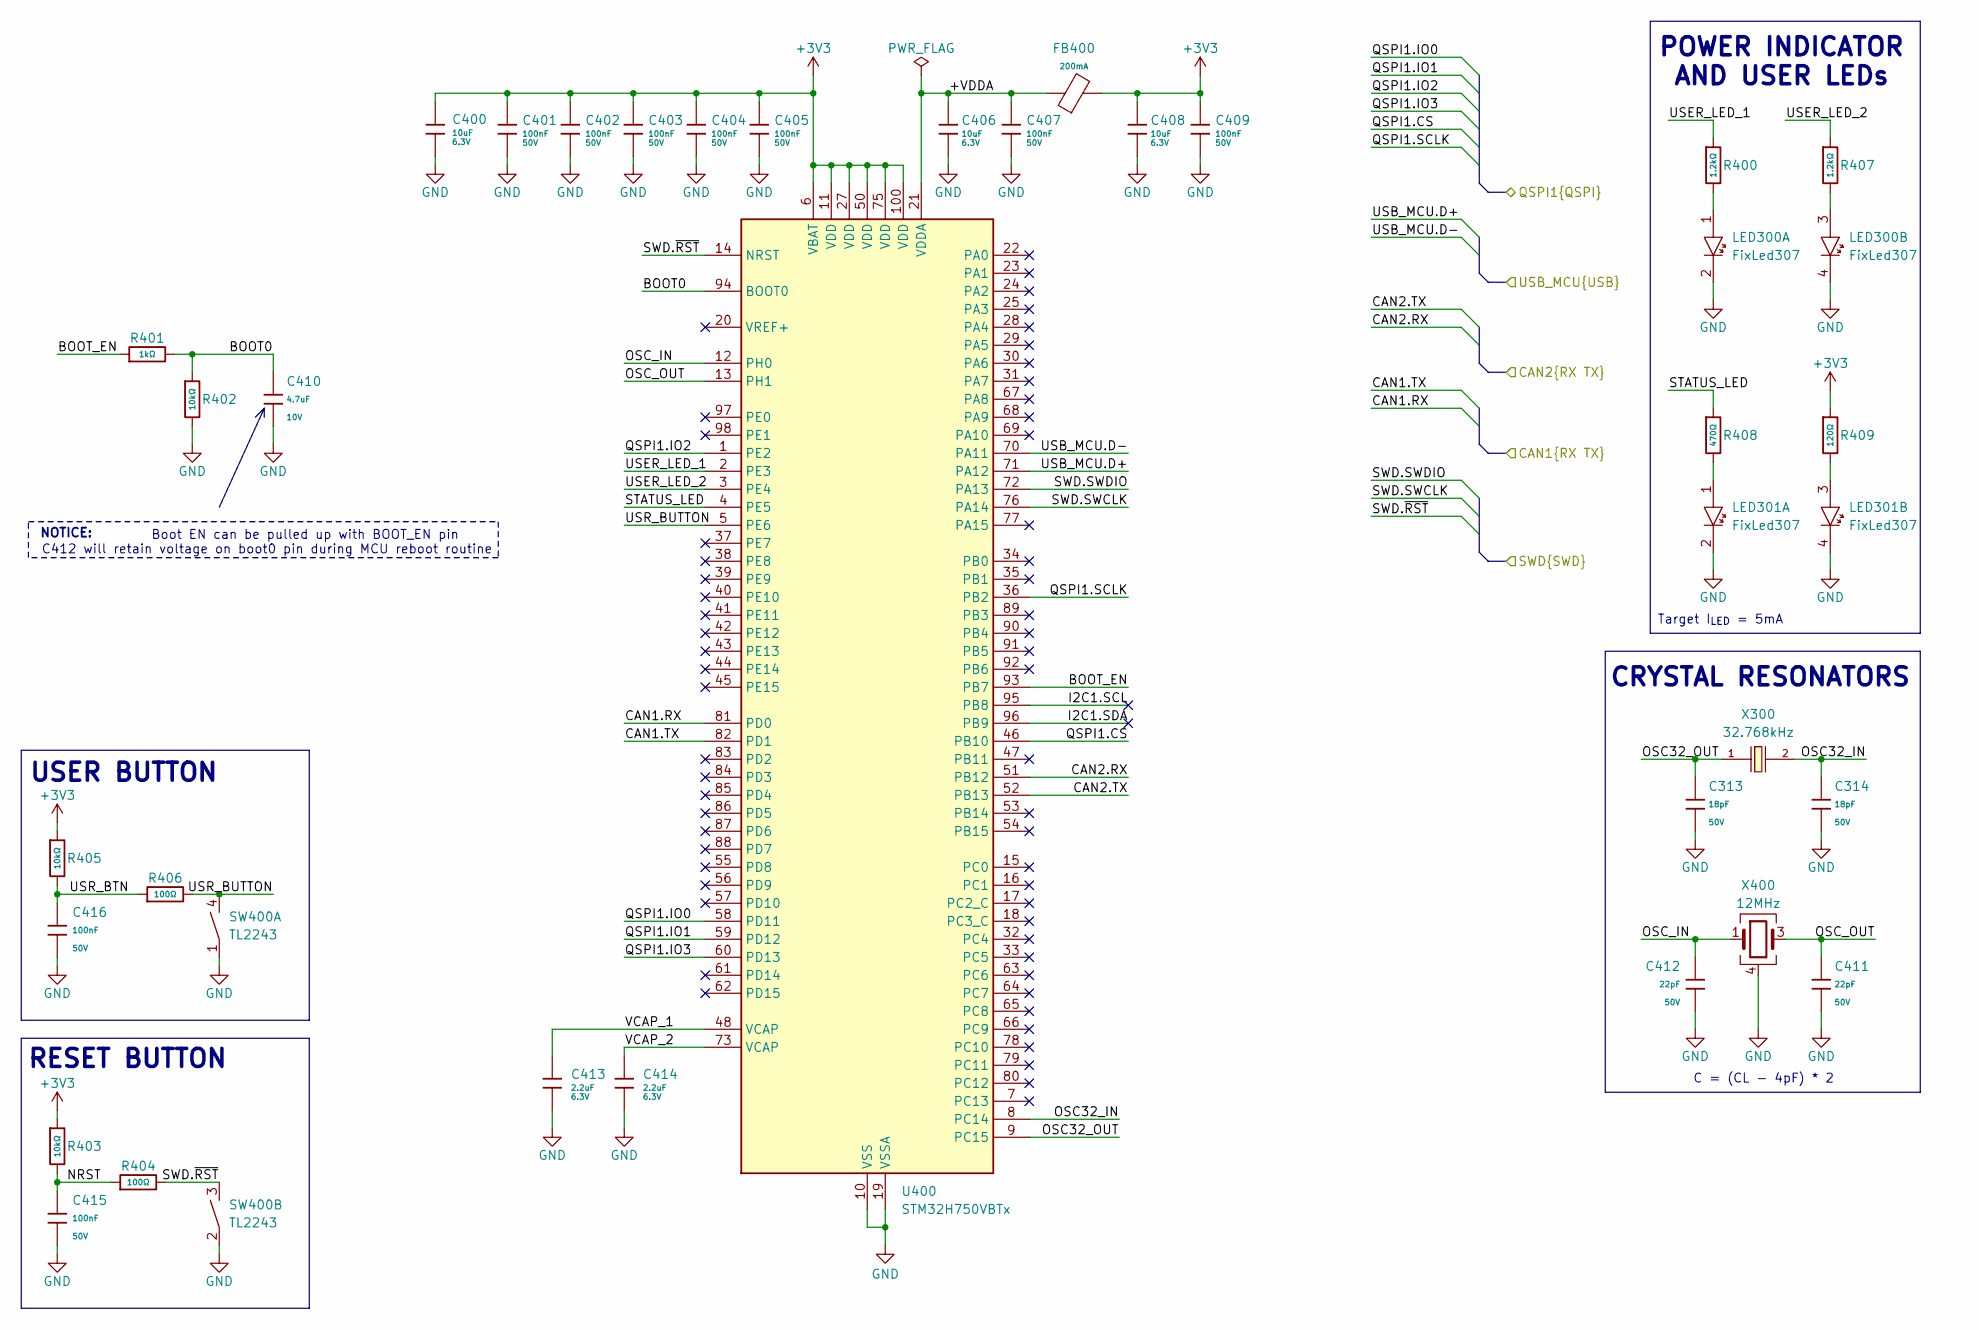
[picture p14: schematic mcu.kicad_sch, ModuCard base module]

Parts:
C313, C314: 18pF; C_0402; Voltage Rated 50V; Tolerance ±5%; Part 0402CG180J500NT; LCSC C1549
C400, C406, C408: 10uF; C_0402; Voltage Rated 6.3V; Tolerance ±20%; Part CL05A106MQ5NUNC; LCSC C15525
C401, C402, C403, C404, C405, C407, C409, C415, C416: 100nF; C_0402; Voltage Rated 50V; Tolerance ±10%; Part CL05B104KB54PNC; LCSC C307331
C410: 4.7uF; C_0402; Voltage Rated 10V; Tolerance ±20%; Part CL05A475MP5NRNC; LCSC C23733
C411, C412: 22pF; C_0402; Voltage Rated 50V; Tolerance ±5%; Part 0402CG220J500NT; LCSC C1555
C413, C414: 2.2uF; C_0402; Voltage Rated 6.3V; Tolerance ±20%; Part CL05A225MQ5NSNC; LCSC C12530
FB400: FB_0603; Current Rating 200mA; Tolerance ±25%; Part GZ1608D601TF; LCSC C1002
LED300, LED301: FixLed307
R400, R407: 1.2kΩ; R_0402; Overload Voltage (Max) 50V; Tolerance ±1%; Part 0402WGF1201TCE; LCSC C25862
R401: 1kΩ; R_0402; Overload Voltage (Max) 50V; Tolerance ±1%; Part 0402WGF1001TCE; LCSC C11702
R402, R403, R405: 10kΩ; R_0402; Overload Voltage (Max) 50V; Tolerance ±1%; Part 0402WGF1002TCE; LCSC C25744
R404, R406: 100Ω; R_0402; Overload Voltage (Max) 50V; Tolerance ±1%; Part 0402WGF1000TCE; LCSC C25076
R408: 470Ω; R_0402; Overload Voltage (Max) 50V; Tolerance ±1%; Part 0402WGF4700TCE; LCSC C25117
R409: 120Ω; R_0402; Overload Voltage (Max) 50V; Tolerance ±1%; Part 0402WGF1200TCE; LCSC C25079
SW400: TL2243
U400: STM32H750VBTx; LQFP-100_14x14mm_P0.5mm
X300: Q13FC1350000400; FC-135R_L3.2-W1.5; Frequency Tolerance ±20ppm; Part Q13FC13500004; LCSC C32346
X400: X322512MSB4SI; CRYSTAL-SMD_4P-L3.2-W2.5-BL; Frequency Tolerance ±10ppm; Part X322512MSB4SI; LCSC C9002

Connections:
+3V3: C400.1, C401.1, C402.1, C403.1, C404.1, C405.1, C408.1, C409.1, FB400.2, R403.1, R405.1, R409.1, U400.6 (VBAT), U400.11 (VDD), U400.27 (VDD), U400.50 (VDD), U400.75 (VDD), U400.100 (VDD); also elsewhere on the board
/CAN transceiver 1/CAN.RX: U400.81 (PD0); also elsewhere on the board
/CAN transceiver 1/CAN.TX: U400.82 (PD1); also elsewhere on the board
/CAN transceiver 2/CAN.RX: U400.51 (PB12); also elsewhere on the board
/CAN transceiver 2/CAN.TX: U400.52 (PB13); also elsewhere on the board
/MCU/+VDDA: C406.1, C407.1, FB400.1, U400.21 (VDDA)
/MCU/BOOT0: C410.1, R401.2, R402.1, U400.94 (BOOT0)
/MCU/BOOT_EN: R401.1, U400.93 (PB7)
/MCU/I2C1.SCL: U400.95 (PB8)
/MCU/I2C1.SDA: U400.96 (PB9)
/MCU/NRST: C415.1, R403.2, R404.1
/MCU/OSC32_IN: C314.1, U400.8 (PC14), X300.2
/MCU/OSC32_OUT: C313.1, U400.9 (PC15), X300.1
/MCU/OSC_IN: C412.1, U400.12 (PH0), X400.1
/MCU/OSC_OUT: C411.1, U400.13 (PH1), X400.3
/MCU/QSPI1.CS: U400.46 (PB10); also elsewhere on the board
/MCU/QSPI1.IO0: U400.58 (PD11); also elsewhere on the board
/MCU/QSPI1.IO1: U400.59 (PD12); also elsewhere on the board
/MCU/QSPI1.IO2: U400.1 (PE2); also elsewhere on the board
/MCU/QSPI1.IO3: U400.60 (PD13); also elsewhere on the board
/MCU/QSPI1.SCLK: U400.36 (PB2); also elsewhere on the board
/MCU/STATUS_LED: R408.1, U400.4 (PE5)
/MCU/SWD.SWCLK: U400.76 (PA14); also elsewhere on the board
/MCU/SWD.SWDIO: U400.72 (PA13); also elsewhere on the board
/MCU/SWD.~RST: R404.2, SW400.3, U400.14 (NRST); also elsewhere on the board
/MCU/USB_MCU.D+: U400.71 (PA12); also elsewhere on the board
/MCU/USB_MCU.D-: U400.70 (PA11); also elsewhere on the board
/MCU/USER_LED_1: R400.1, U400.2 (PE3)
/MCU/USER_LED_2: R407.1, U400.3 (PE4)
/MCU/USR_BTN: C416.1, R405.2, R406.1
/MCU/USR_BUTTON: R406.2, SW400.4, U400.5 (PE6)
/MCU/VCAP_1: C413.1, U400.48 (VCAP)
/MCU/VCAP_2: C414.1, U400.73 (VCAP)
GND: C313.2, C314.2, C400.2, C401.2, C402.2, C403.2, C404.2, C405.2, C406.2, C407.2, C408.2, C409.2, C410.2, C411.2, C412.2, C413.2, C414.2, C415.2, C416.2, LED300.2, LED300.4, LED301.2, LED301.4, R402.2, SW400.1, SW400.2, U400.10 (VSS), U400.19 (VSSA), U400.26 (VSS), U400.49 (VSS), U400.74 (VSS), U400.99 (VSS), X400.2, X400.4; also elsewhere on the board
unnamed: LED300.1, R400.2
unnamed: LED300.3, R407.2
unnamed: LED301.1, R408.2
unnamed: LED301.3, R409.2

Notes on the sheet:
Boot EN can be pulled up with BOOT_EN pin C412 will retain voltage on boot0 pin during MCU reboot routine
RESET BUTTON
C = (CL - 4pF) * 2
CRYSTAL RESONATORS
POWER INDICATOR AND USER LEDs
NOTICE:
Target I_{LED} = 5mA
USER BUTTON

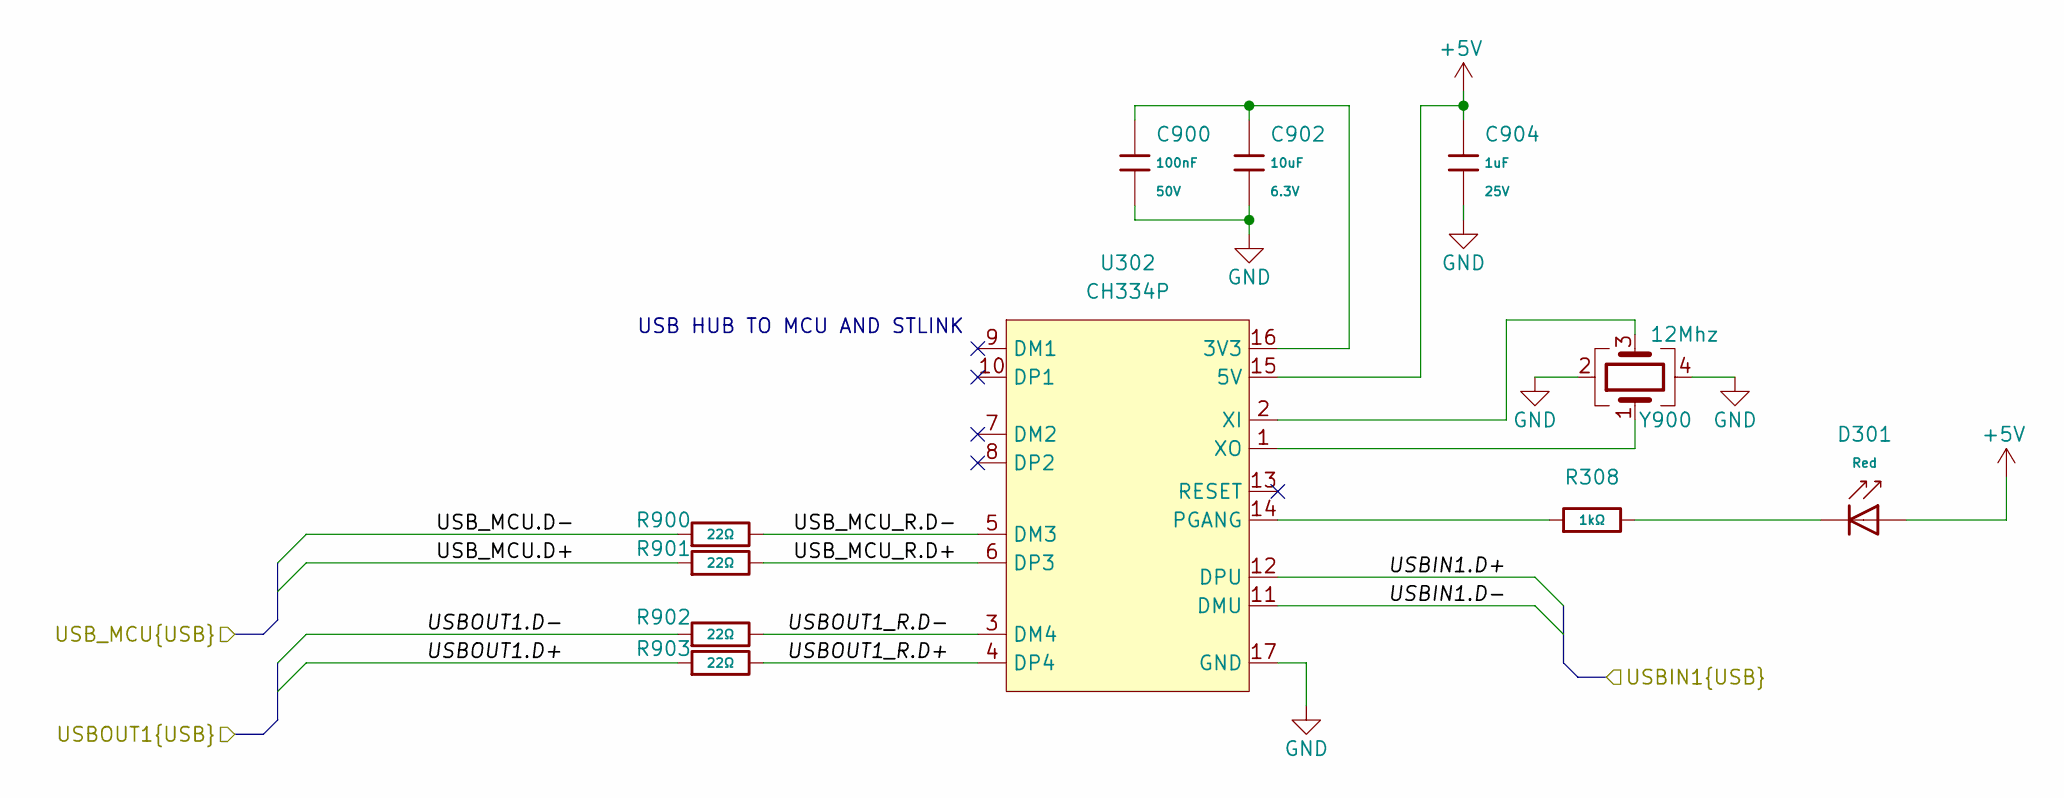
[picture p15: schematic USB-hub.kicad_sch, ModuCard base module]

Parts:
C900: 100nF; C_0402; Voltage Rated 50V; Tolerance ±10%; Part CL05B104KB54PNC; LCSC C307331
C902: 10uF; C_0402; Voltage Rated 6.3V; Tolerance ±20%; Part CL05A106MQ5NUNC; LCSC C15525
C904: 1uF; C_0402; Voltage Rated 25V; Tolerance ±10%; Part CL05A105KA5NQNC; LCSC C52923
D301: Red; D_0603; Part KT-0603R; LCSC C2286
R308: 1kΩ; R_0402; Overload Voltage (Max) 50V; Tolerance ±1%; Part 0402WGF1001TCE; LCSC C11702
R900, R901, R902, R903: 22Ω; R_0402; Overload Voltage (Max) 50V; Tolerance ±1%; Part 0402WGF220JTCE; LCSC C25092
U302: CH334P; QFN-16-1EP_3x3mm_P0.5mm_EP1.7x1.7mm
Y900: 12Mhz; Crystal_SMD_3225-4Pin_3.2x2.5mm

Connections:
+5V: C904.1, D301.2, U302.15 (5V); also elsewhere on the board
/MCU/USB_MCU.D+: R901.1; also elsewhere on the board
/MCU/USB_MCU.D-: R900.1; also elsewhere on the board
/ST-LINK/ST-LINK.D+: R903.1; also elsewhere on the board
/ST-LINK/ST-LINK.D-: R902.1; also elsewhere on the board
/USB-hub/USBIN1.D+: U302.12 (DPU); also elsewhere on the board
/USB-hub/USBIN1.D-: U302.11 (DMU); also elsewhere on the board
/USB-hub/USBOUT1_R.D+: R903.2, U302.4 (DP4)
/USB-hub/USBOUT1_R.D-: R902.2, U302.3 (DM4)
/USB-hub/USB_MCU_R.D+: R901.2, U302.6 (DP3)
/USB-hub/USB_MCU_R.D-: R900.2, U302.5 (DM3)
GND: C900.2, C902.2, C904.2, U302.17 (GND), Y900.2, Y900.4; also elsewhere on the board
unnamed: D301.1, R308.2
unnamed: C900.1, C902.1, U302.16 (3V3)
unnamed: R308.1, U302.14 (PGANG)
unnamed: U302.2 (XI), Y900.3
unnamed: U302.1 (XO), Y900.1

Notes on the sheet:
USB HUB TO MCU AND STLINK

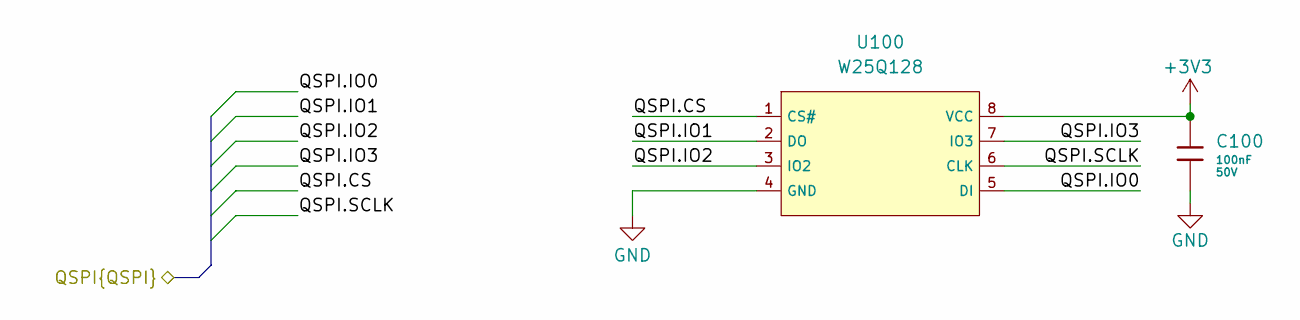
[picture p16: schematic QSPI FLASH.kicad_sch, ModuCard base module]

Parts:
C100: 100nF; C_0402; Voltage Rated 50V; Tolerance ±10%; Part CL05B104KB54PNC; LCSC C307331
U100: W25Q128; SOIC-8_L5.3-W5.3-P1.27-LS8.0-BL; Part W25Q128JVSIQ; LCSC C97521

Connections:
+3V3: C100.1, U100.8 (VCC); also elsewhere on the board
/MCU/QSPI1.CS: U100.1 (CS#); also elsewhere on the board
/MCU/QSPI1.IO0: U100.5 (DI); also elsewhere on the board
/MCU/QSPI1.IO1: U100.2 (DO); also elsewhere on the board
/MCU/QSPI1.IO2: U100.3 (IO2); also elsewhere on the board
/MCU/QSPI1.IO3: U100.7 (IO3); also elsewhere on the board
/MCU/QSPI1.SCLK: U100.6 (CLK); also elsewhere on the board
GND: C100.2, U100.4 (GND); also elsewhere on the board

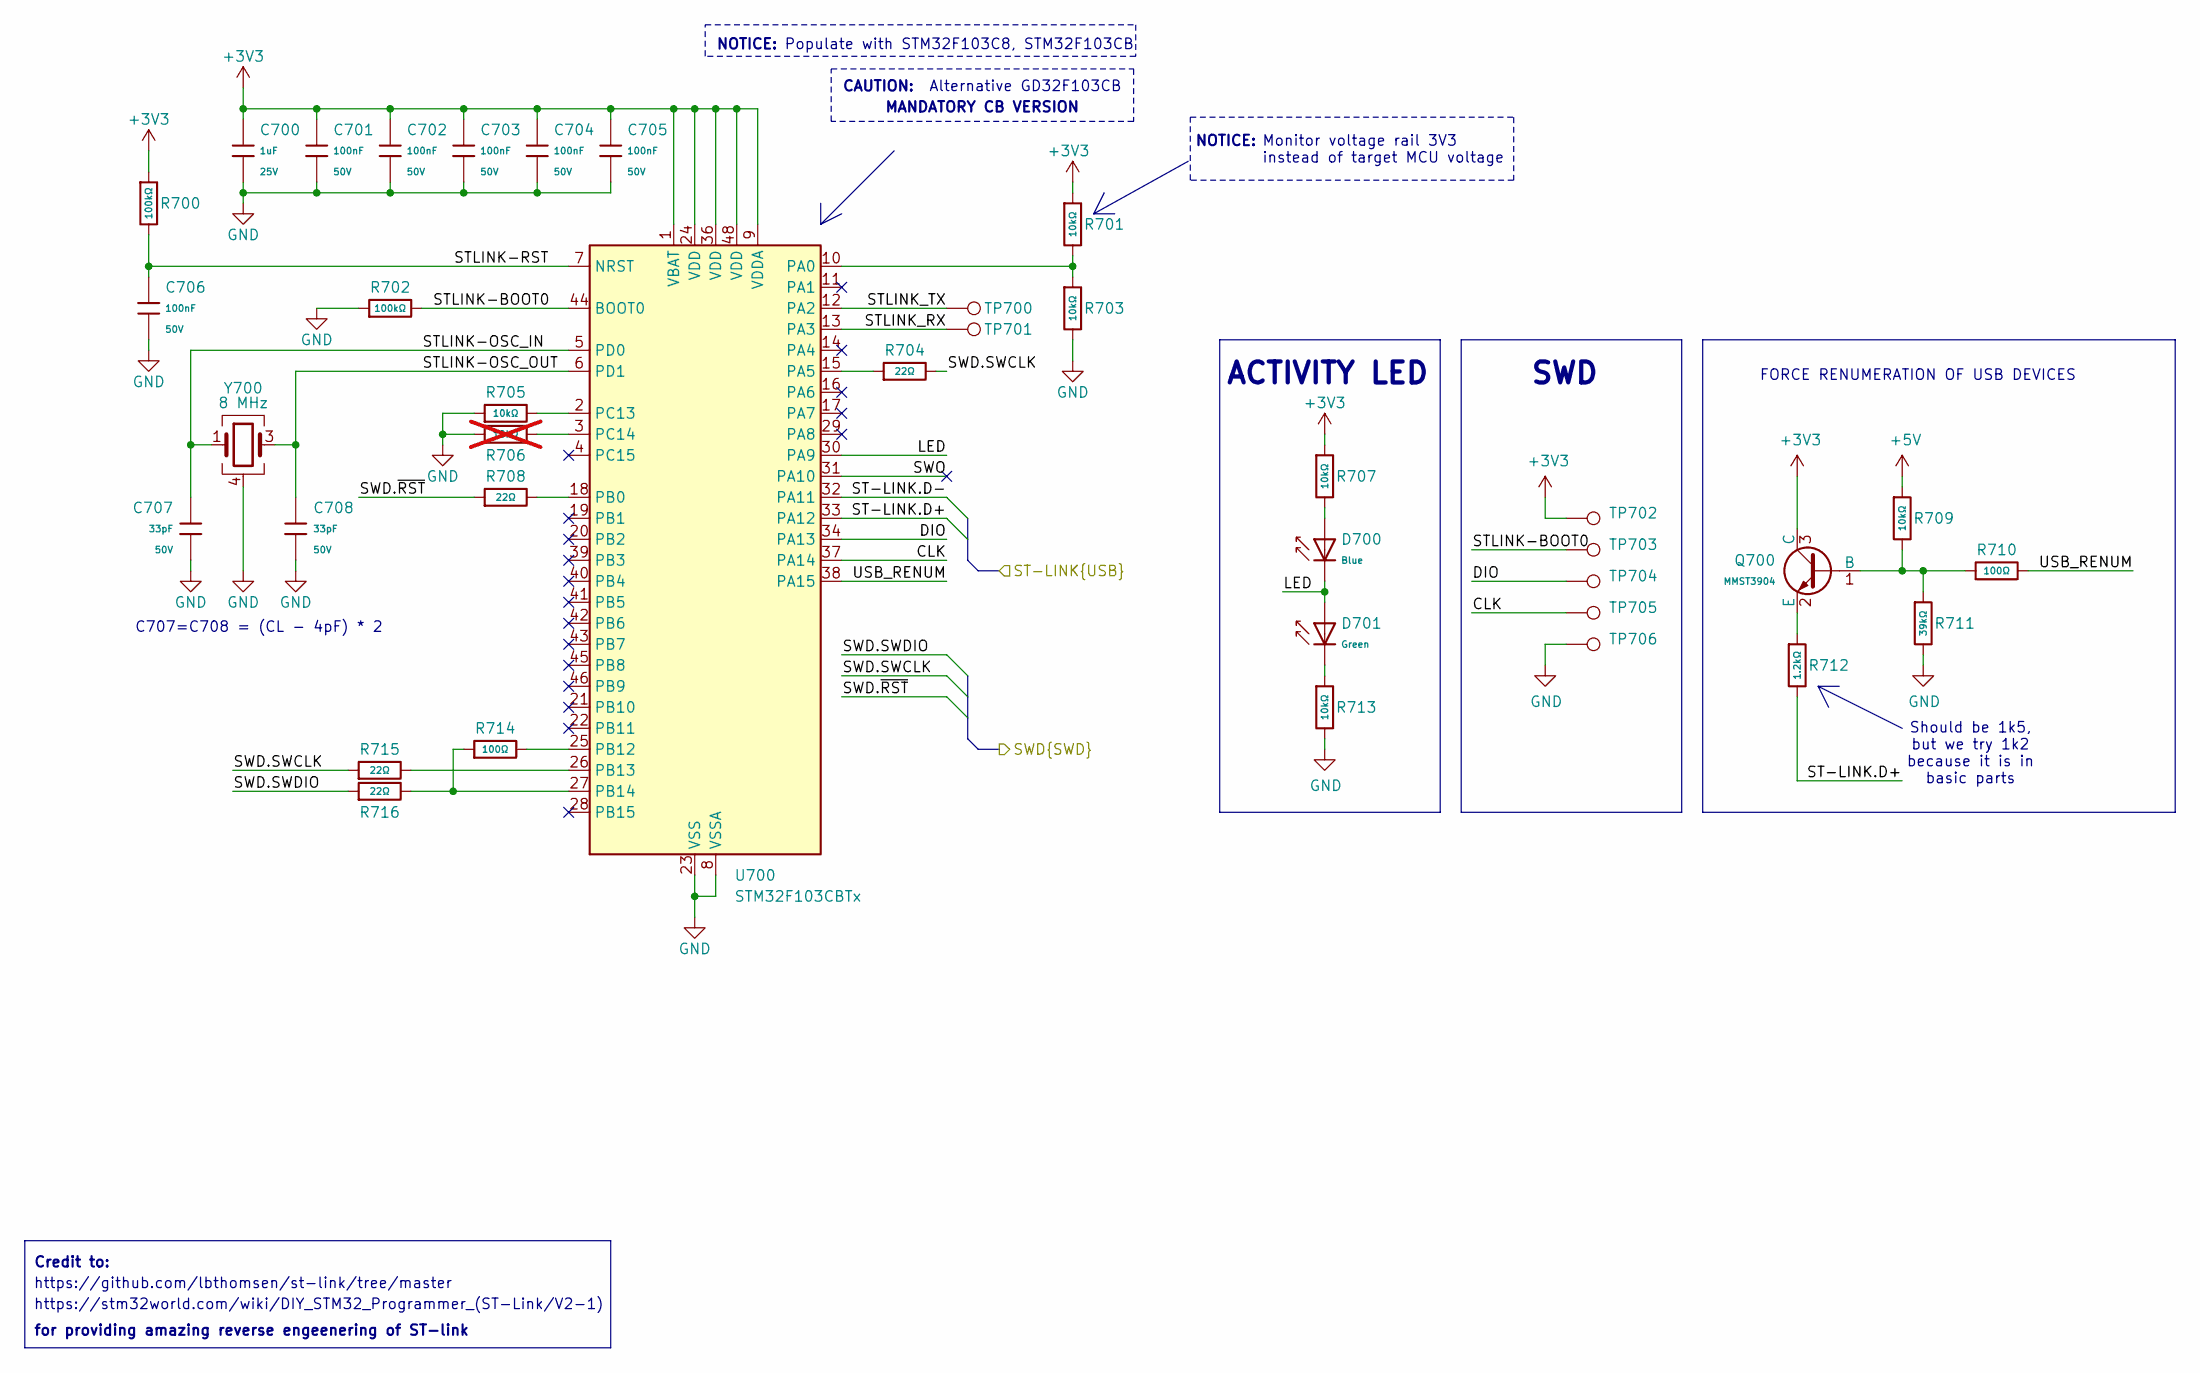
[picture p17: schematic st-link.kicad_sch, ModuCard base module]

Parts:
C700: 1uF; C_0402; Voltage Rated 25V; Tolerance ±10%; Part CL05A105KA5NQNC; LCSC C52923
C701, C702, C703, C704, C705, C706: 100nF; C_0402; Voltage Rated 50V; Tolerance ±10%; Part CL05B104KB54PNC; LCSC C307331
C707, C708: 33pF; C_0402; Voltage Rated 50V; Tolerance ±5%; Part 0402CG330J500NT; LCSC C1562
D700: Blue; D_0603; Part 19-217/BHC-ZL1M2RY/6T; LCSC C2986058
D701: Green; D_0603; Part 19-217/GHC-YR1S2/6T; LCSC C2986059
Q700: MMST3904; Q_SOT-323; Part MMST3904; LCSC C22388837
R700, R702: 100kΩ; R_0402; Overload Voltage (Max) 50V; Tolerance ±1%; Part 0402WGF1003TCE; LCSC C25741
R701, R703, R705, R707, R709, R713: 10kΩ; R_0402; Overload Voltage (Max) 50V; Tolerance ±1%; Part 0402WGF1002TCE; LCSC C25744
R704, R708, R715, R716: 22Ω; R_0402; Overload Voltage (Max) 50V; Tolerance ±1%; Part 0402WGF220JTCE; LCSC C25092
R706: 10kΩ; R_0402; Overload Voltage (Max) 50V; Tolerance ±1%; Part 0402WGF1002TCE; LCSC C25744; not fitted
R710, R714: 100Ω; R_0402; Overload Voltage (Max) 50V; Tolerance ±1%; Part 0402WGF1000TCE; LCSC C25076
R711: 39kΩ; R_0402; Overload Voltage (Max) 50V; Tolerance ±1%; Part 0402WGF3902TCE; LCSC C25783
R712: 1.2kΩ; R_0402; Overload Voltage (Max) 50V; Tolerance ±1%; Part 0402WGF1201TCE; LCSC C25862
TP700, TP701: TestPoint; TestPoint_Pad_D1.0mm
TP702, TP703, TP704, TP705, TP706: TestPoint_Pad_D1.0mm
U700: STM32F103CBTx; LQFP-48_7x7mm_P0.5mm
Y700: 8 MHz; CRYSTAL-SMD_4P-L3.2-W2.5-BL; MPN 3225-8.00-20-10-10/4B; LCSC C7424755

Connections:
+3V3: C700.1, C701.1, C702.1, C703.1, C704.1, C705.1, Q700.3 (C), R700.1, R701.1, R707.1, TP702.1, U700.1 (VBAT), U700.9 (VDDA), U700.24 (VDD), U700.36 (VDD), U700.48 (VDD); also elsewhere on the board
+5V: R709.1; also elsewhere on the board
/MCU/SWD.SWCLK: R704.2, R715.1; also elsewhere on the board
/MCU/SWD.SWDIO: R716.1; also elsewhere on the board
/MCU/SWD.~RST: R708.1; also elsewhere on the board
/ST-LINK/CLK: TP705.1, U700.37 (PA14)
/ST-LINK/DIO: TP704.1, U700.34 (PA13)
/ST-LINK/LED: D700.1, D701.2, U700.30 (PA9)
/ST-LINK/ST-LINK.D+: R712.2, U700.33 (PA12); also elsewhere on the board
/ST-LINK/ST-LINK.D-: U700.32 (PA11); also elsewhere on the board
/ST-LINK/STLINK-BOOT0: R702.2, TP703.1, U700.44 (BOOT0)
/ST-LINK/STLINK-OSC_IN: C707.1, U700.5 (PD0), Y700.1
/ST-LINK/STLINK-OSC_OUT: C708.1, U700.6 (PD1), Y700.3
/ST-LINK/STLINK-RST: C706.1, R700.2, U700.7 (NRST)
/ST-LINK/STLINK_RX: TP701.1, U700.13 (PA3)
/ST-LINK/STLINK_TX: TP700.1, U700.12 (PA2)
/ST-LINK/SWO: U700.31 (PA10)
/ST-LINK/USB_RENUM: R710.2, U700.38 (PA15)
GND: C700.2, C701.2, C702.2, C703.2, C704.2, C705.2, C706.2, C707.2, C708.2, R702.1, R703.2, R705.1, R706.1, R711.2, R713.2, TP706.1, U700.8 (VSSA), U700.23 (VSS), U700.35 (VSS), U700.47 (VSS), Y700.2, Y700.4; also elsewhere on the board
unnamed: D700.2, R707.2
unnamed: D701.1, R713.1
unnamed: Q700.1 (B), R709.2, R710.1, R711.1
unnamed: Q700.2 (E), R712.1
unnamed: R701.2, R703.1, U700.10 (PA0)
unnamed: R704.1, U700.15 (PA5)
unnamed: R708.2, U700.18 (PB0)
unnamed: R714.2, U700.25 (PB12)
unnamed: R715.2, U700.26 (PB13)
unnamed: R714.1, R716.2, U700.27 (PB14)
unnamed: R705.2, U700.2 (PC13)
unnamed: R706.2, U700.3 (PC14)

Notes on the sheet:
Alternative GD32F103CB
SWD
NOTICE:
C707=C708 = (CL - 4pF) * 2
Monitor voltage rail 3V3 instead of target MCU voltage
https://stm32world.com/wiki/DIY_STM32_Programmer_(ST-Link/V2-1)
CAUTION:
Populate with STM32F103C8, STM32F103CB
Should be 1k5, but we try 1k2 because it is in basic parts
ACTIVITY LED
for providing amazing reverse engeenering of ST-link
MANDATORY CB VERSION
FORCE RENUMERATION OF USB DEVICES
https://github.com/lbthomsen/st-link/tree/master
Credit to:

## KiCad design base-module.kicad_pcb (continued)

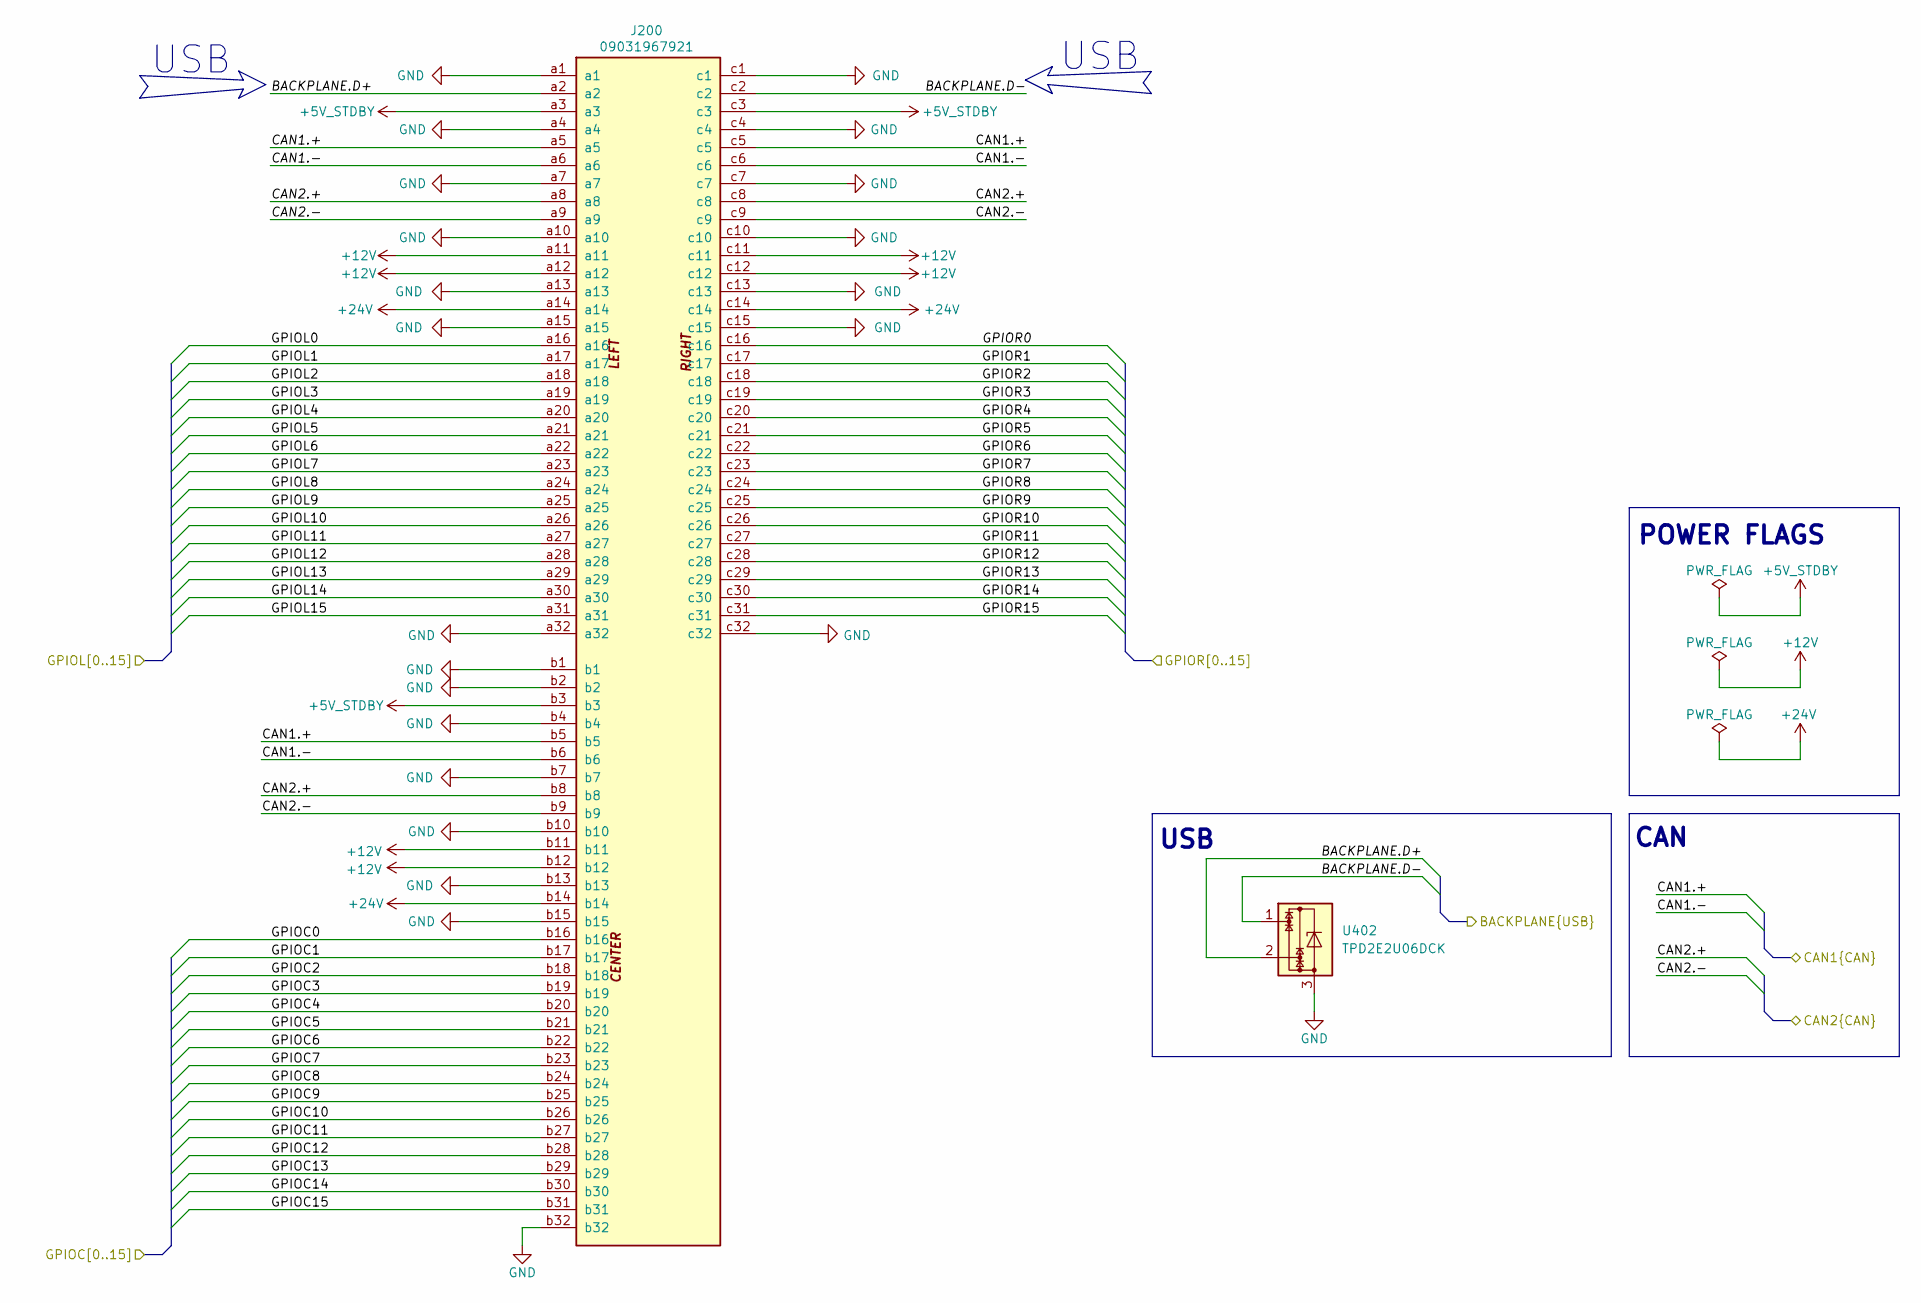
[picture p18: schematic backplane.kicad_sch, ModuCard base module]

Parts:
J200: 09031967921; DIN41612_R_3x32_Female_Horizontal_THT; PARTREV D
U402: TPD2E2U06DCK; SOT-323_SC-70

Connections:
+5V_STDBY: J200.a3, J200.b3, J200.c3
+12V: J200.a11, J200.a12, J200.b11, J200.b12, J200.c11, J200.c12; also elsewhere on the board
+24V: J200.a14, J200.b14, J200.c14
/Backplane/BACKPLANE.D+: J200.a2, U402.2; also elsewhere on the board
/Backplane/BACKPLANE.D-: J200.c2, U402.1; also elsewhere on the board
/Backplane/CAN1.+: J200.a5, J200.b5, J200.c5; also elsewhere on the board
/Backplane/CAN1.-: J200.a6, J200.b6, J200.c6; also elsewhere on the board
/Backplane/CAN2.+: J200.a8, J200.b8, J200.c8; also elsewhere on the board
/Backplane/CAN2.-: J200.a9, J200.b9, J200.c9; also elsewhere on the board
/Backplane/GPIOC0: J200.b16
/Backplane/GPIOC1: J200.b17
/Backplane/GPIOC2: J200.b18
/Backplane/GPIOC3: J200.b19
/Backplane/GPIOC4: J200.b20
/Backplane/GPIOC5: J200.b21
/Backplane/GPIOC6: J200.b22
/Backplane/GPIOC7: J200.b23
/Backplane/GPIOC8: J200.b24
/Backplane/GPIOC9: J200.b25
/Backplane/GPIOC10: J200.b26
/Backplane/GPIOC11: J200.b27
/Backplane/GPIOC12: J200.b28
/Backplane/GPIOC13: J200.b29
/Backplane/GPIOC14: J200.b30
/Backplane/GPIOC15: J200.b31
/Backplane/GPIOL0: J200.a16
/Backplane/GPIOL1: J200.a17
/Backplane/GPIOL2: J200.a18
/Backplane/GPIOL3: J200.a19
/Backplane/GPIOL4: J200.a20
/Backplane/GPIOL5: J200.a21
/Backplane/GPIOL6: J200.a22
/Backplane/GPIOL7: J200.a23
/Backplane/GPIOL8: J200.a24
/Backplane/GPIOL9: J200.a25
/Backplane/GPIOL10: J200.a26
/Backplane/GPIOL11: J200.a27
/Backplane/GPIOL12: J200.a28
/Backplane/GPIOL13: J200.a29
/Backplane/GPIOL14: J200.a30
/Backplane/GPIOL15: J200.a31
/Backplane/GPIOR0: J200.c16
/Backplane/GPIOR1: J200.c17
/Backplane/GPIOR2: J200.c18
/Backplane/GPIOR3: J200.c19
/Backplane/GPIOR4: J200.c20
/Backplane/GPIOR5: J200.c21
/Backplane/GPIOR6: J200.c22
/Backplane/GPIOR7: J200.c23
/Backplane/GPIOR8: J200.c24
/Backplane/GPIOR9: J200.c25
/Backplane/GPIOR10: J200.c26
/Backplane/GPIOR11: J200.c27
/Backplane/GPIOR12: J200.c28
/Backplane/GPIOR13: J200.c29
/Backplane/GPIOR14: J200.c30
/Backplane/GPIOR15: J200.c31
GND: J200.a1, J200.a4, J200.a7, J200.a10, J200.a13, J200.a15, J200.a32, J200.b1, J200.b2, J200.b4, J200.b7, J200.b10, J200.b13, J200.b15, J200.b32, J200.c1, J200.c4, J200.c7, J200.c10, J200.c13, J200.c15, J200.c32, U402.3; also elsewhere on the board

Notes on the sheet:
USB
CAN
POWER FLAGS
USB

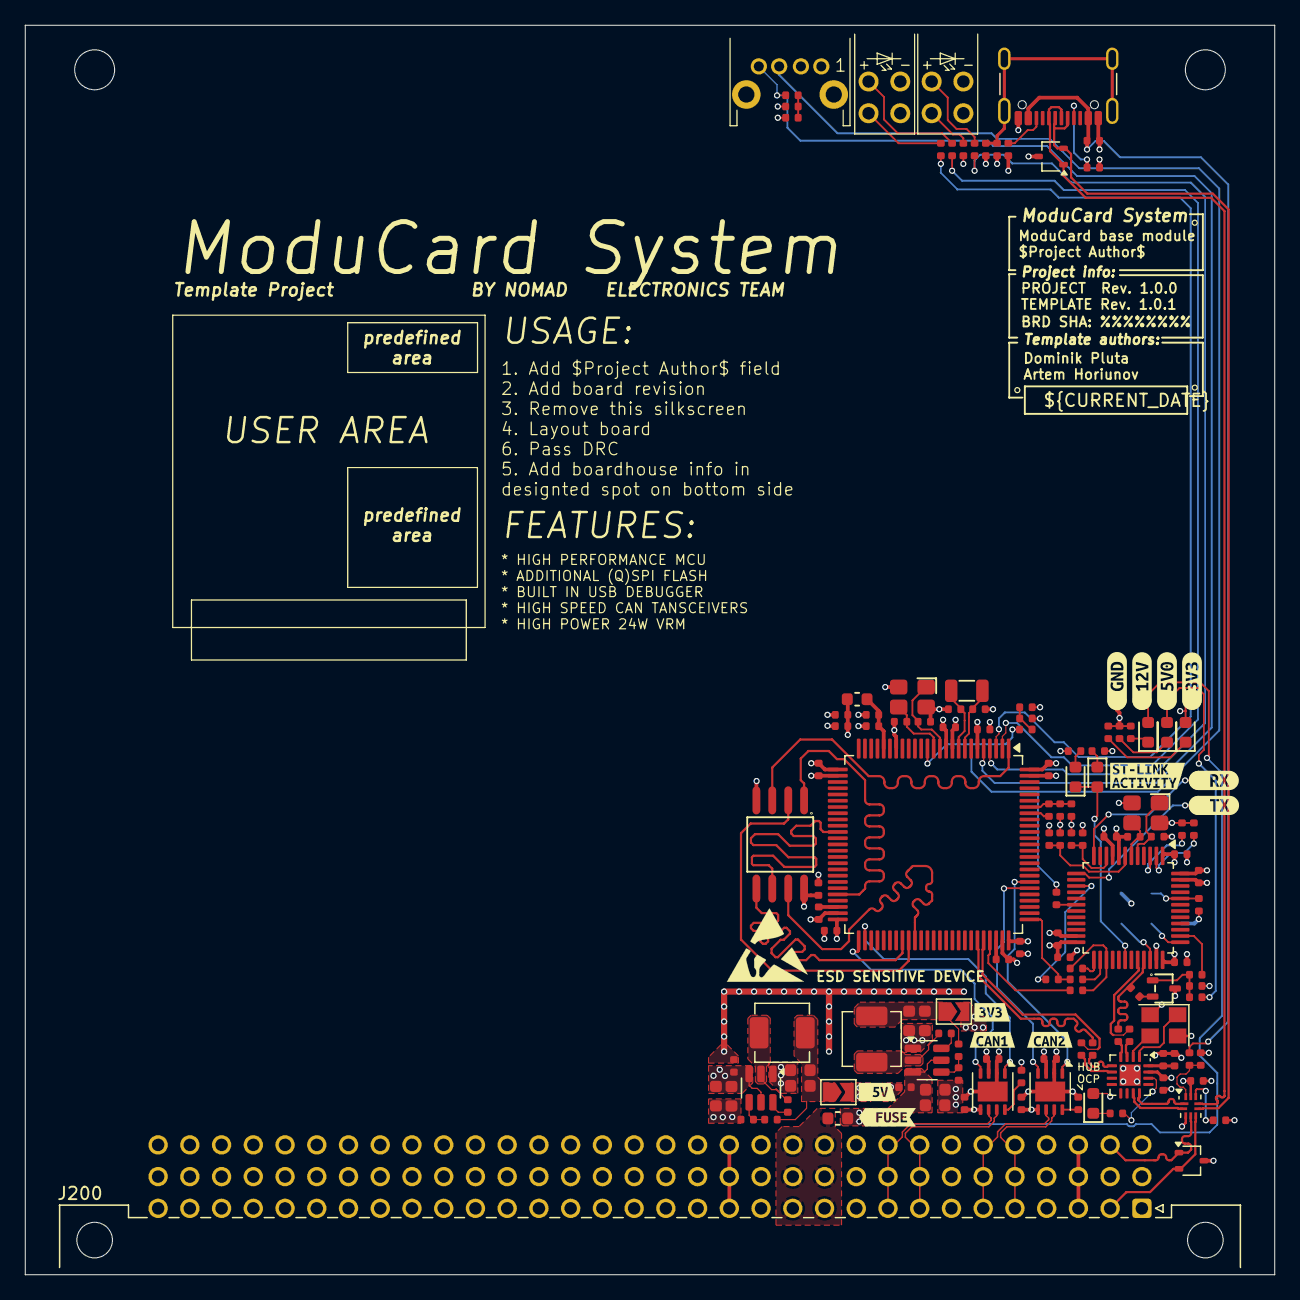
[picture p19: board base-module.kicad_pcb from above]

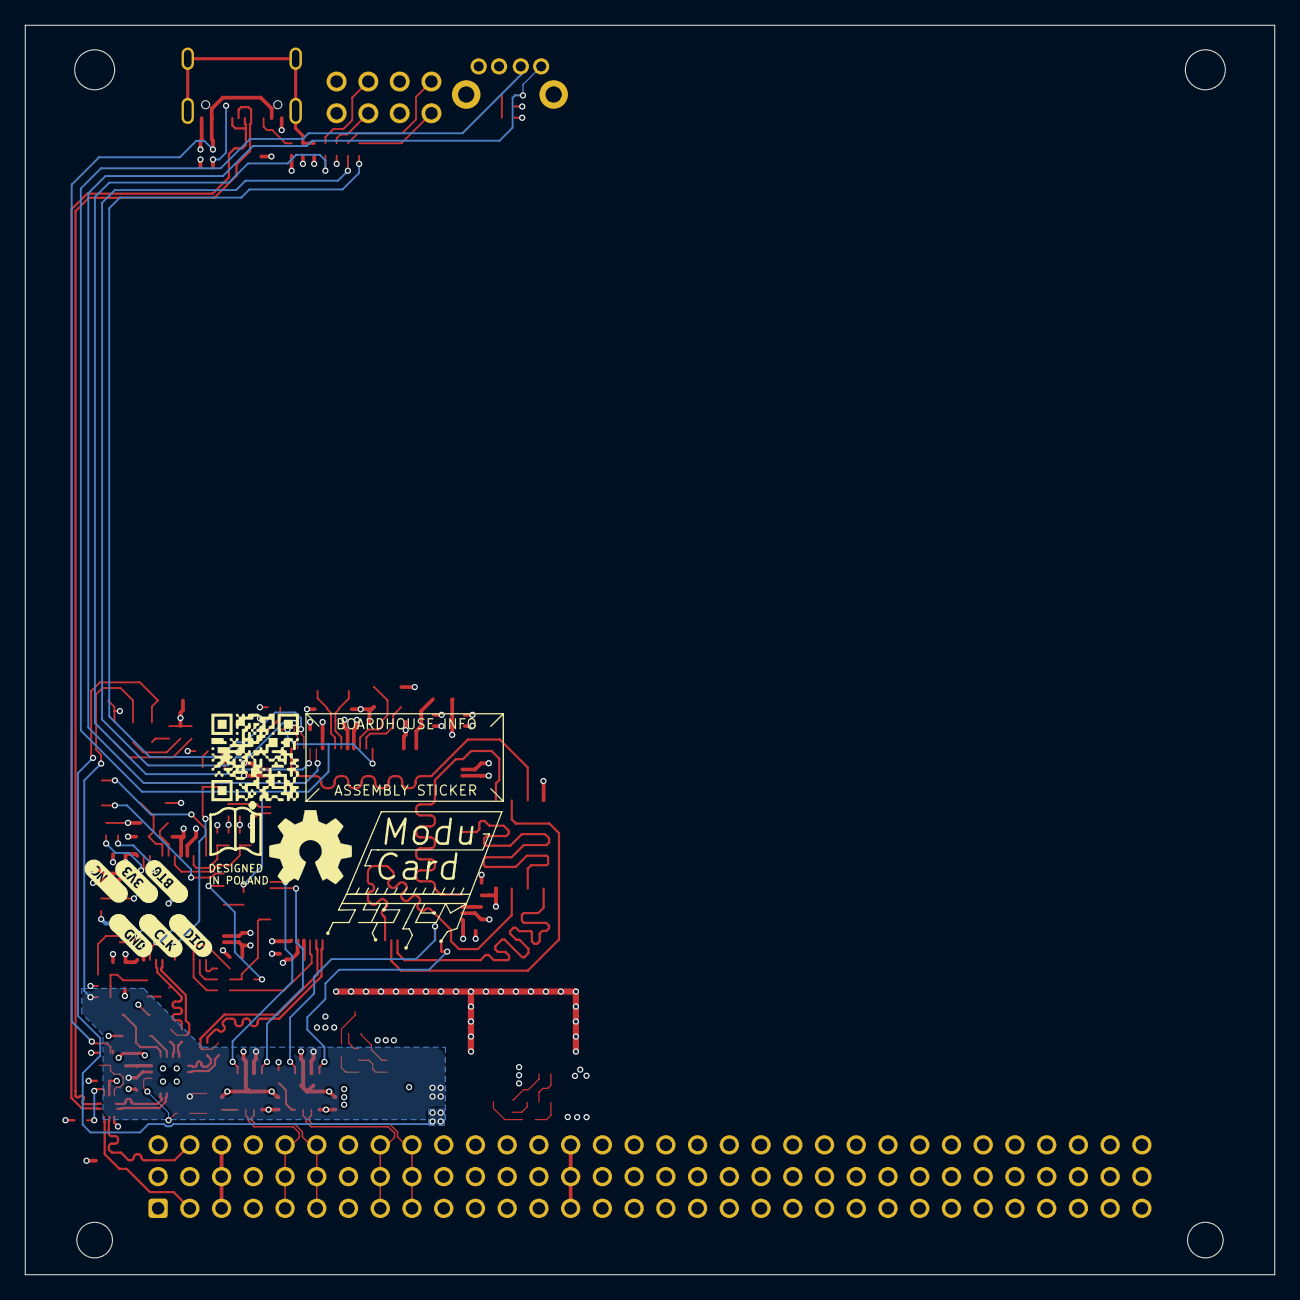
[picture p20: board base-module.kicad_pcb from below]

Board: 4 copper layers, 100.0 x 100.0 mm, 160 parts (11 on the bottom side), 103 nets.

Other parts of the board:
kibuzzard-67B20BD5: G***; kibuzzard-67B20BD5
kibuzzard-67B63E8D: G***; kibuzzard-67B63E8D
kibuzzard-67B219C6: G***; kibuzzard-67B219C6
kibuzzard-67B624A4: G***; kibuzzard-67B624A4
kibuzzard-67B643AC: G***; kibuzzard-67B643AC
kibuzzard-67B643DE: G***; kibuzzard-67B643DE
kibuzzard-67B643EE: G***; kibuzzard-67B643EE
kibuzzard-67B2198C: G***; kibuzzard-67B2198C
kibuzzard-67B6248A: G***; kibuzzard-67B6248A
kibuzzard-67B6249A: G***; kibuzzard-67B6249A
kibuzzard-67B6438D: G***; kibuzzard-67B6438D
kibuzzard-67B37005: G***; kibuzzard-67B37005
kibuzzard-67B37418: G***; kibuzzard-67B37418
kibuzzard-67B37472: G***; kibuzzard-67B37472
kibuzzard-67B62451: G***; kibuzzard-67B62451
kibuzzard-67B62470: G***; kibuzzard-67B62470
kibuzzard-67BE3F52: G***; kibuzzard-67BE3F52
kibuzzard-67E7D86B: G***; kibuzzard-67E7D86B

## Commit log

2025-04-18 Revert "1 change mcu schematic "
    [QSPI FLASH.kicad_sch, USB-hub.kicad_sch, USB.kicad_sch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]
2025-04-18 Add generated schematic PDF and Gerber files
    [base-module-B_Cu.gbr, base-module-B_Mask.gbr, base-module-B_Paste.gbr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]
